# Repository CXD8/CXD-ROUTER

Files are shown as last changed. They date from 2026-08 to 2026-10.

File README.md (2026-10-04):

# CXD-ROUTER
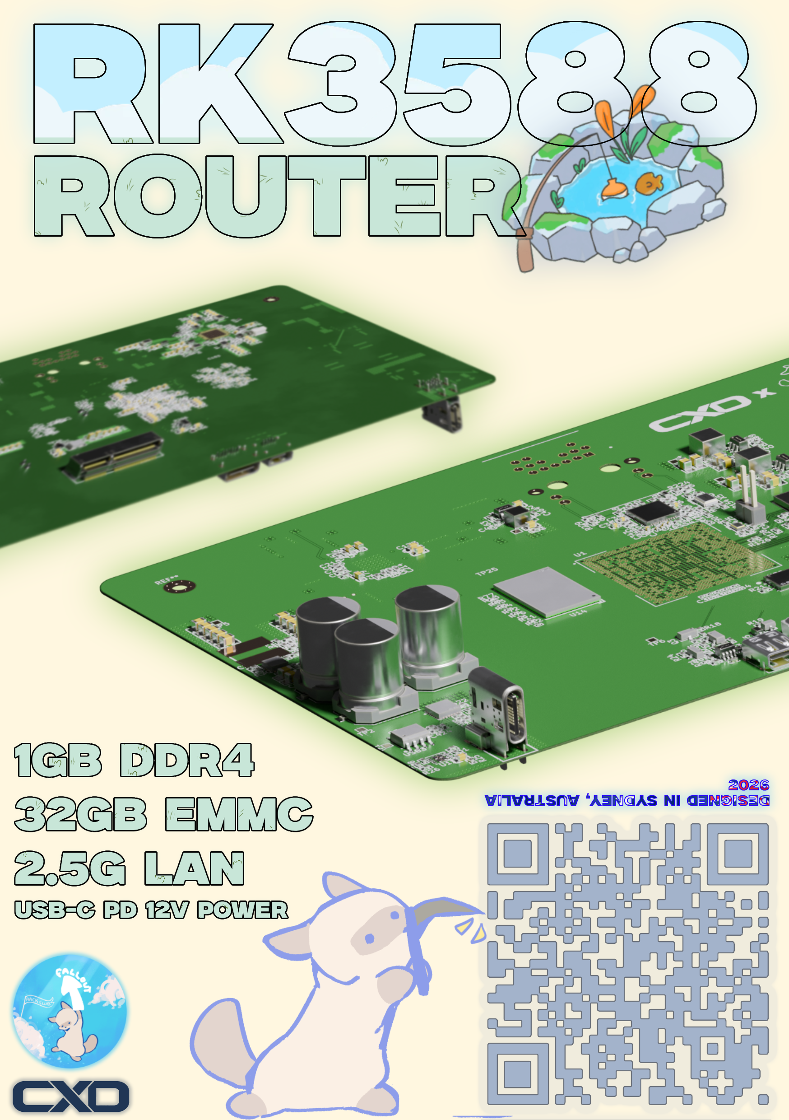
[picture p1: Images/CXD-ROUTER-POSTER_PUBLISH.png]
Poster


CXD-ROUTER is a high-speed, modular router built on a Rockchip RK3588 SoC, powered by USB-C PD.

Goal of Project:
Most consumer routers are locked down and unupgrade. I built this as a high-performance router where networking hardware (e.g., m.2 Wi-Fi modules) can be easily upgraded using M.2 slots without replacing the entire device.

## Specifications and Features

| Component | Details |
| :--- | :--- |
| **SoC** | Rockchip RK3588 |
| **Memory** | Onboard LPDDR4 memory |
| **Storage** | Onboard eMMC storage |
| **Upgradable Modules** | M.2 slots for 2.5GbE Ethernet and BE3600 Wi-Fi cards |
| **Power** | USB-C Power Delivery (PD) 12V |
| **I/O** | Mini HDMI, USB-C, 2.5G RJ45 |

## Firmware, flashing and setup

1. Follow Firefly's or Fygo's existing documentation to flash the RK3588 board (image itself cant be uploaded here due to size; flashing tools included in firmware folder):  
   [Fygo ROC-RK3588-PC Upgrade Firmware Guide](https://help.fygonas.com/articles/v1/contact/arm-rk-usb)  
   [Firefly ROC-RK3588-PC Upgrade Firmware Guide](https://wiki.t-firefly.com/en/ROC-RK3588-PC/upgrade_firmware.html)  
3. Connect peripherals (OPT: M.2 WiFi Card)
4. Plug in your network cable and Mini HDMI to a monitor.
5. Connect a 12v USB-C PD compatible power source to the board.

## Images
 **PCB:**
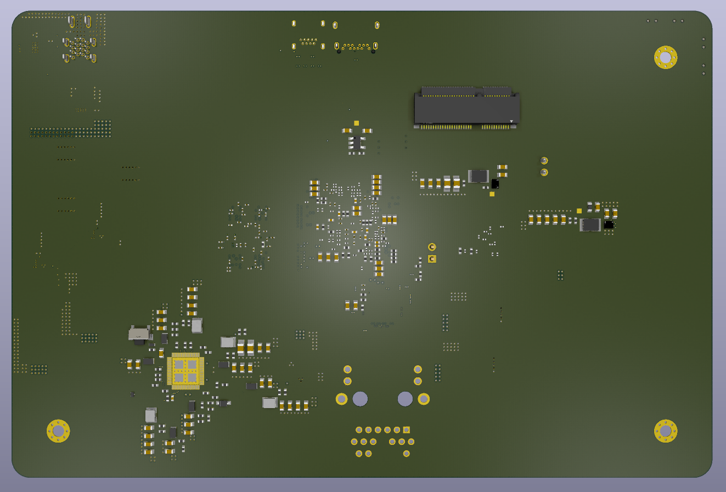
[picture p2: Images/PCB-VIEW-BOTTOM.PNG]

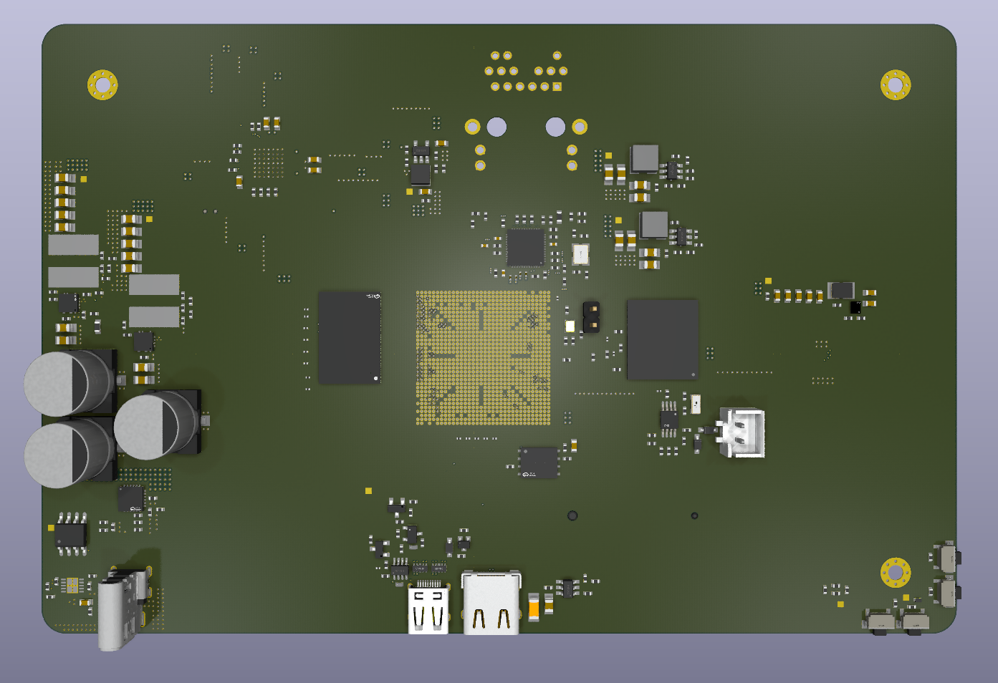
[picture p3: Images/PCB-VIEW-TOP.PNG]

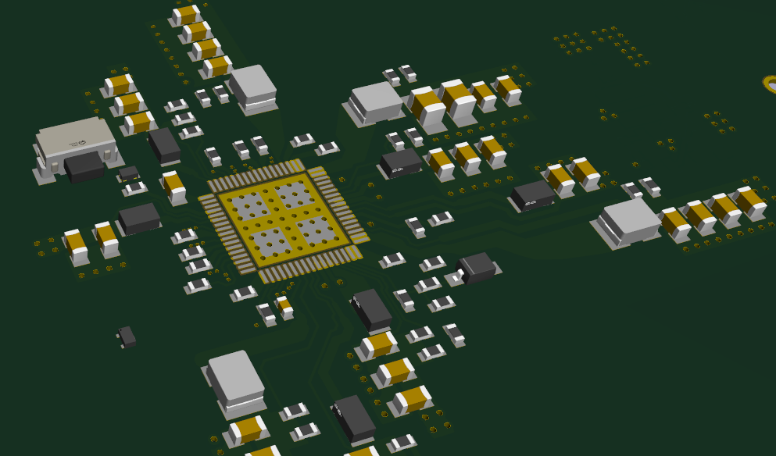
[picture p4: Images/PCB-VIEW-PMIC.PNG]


 **Housing:**
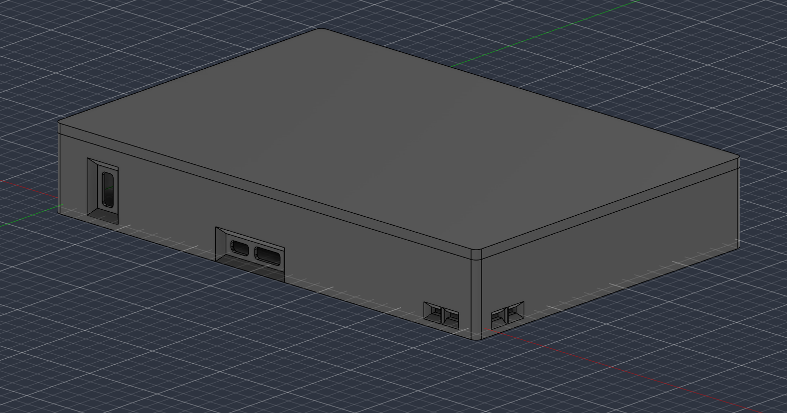
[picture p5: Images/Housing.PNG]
Housing


## Bill of Materials
|CXD-ROUTER-V1.0.0.csv| | | | | | | | | | | | | | | |
|---|---|---|---|---|---|---|---|---|---|---|---|---|---|---|---|
| | | | | | | | | | | | | | | | |
| | | | | | | | | | | | | | | | |
|Uploaded data | | | | | | | | | | | | | | | |
|LCSC# |Mrf# |Description |Package |Value |Quantity|Mfr. |Order Qty.|Unit Price(USD)|Ext.Price(USD)|Package |Min |Mult |SPQ |Description |Product Link |
|C49062 |CL03A104KP3NNNC |100nF X5R 10V 0201 |CL03A104KP3NNNC | |46 |Samsung Electro-Mechanics|100 |0.0047 |0.47 |0201 |100 |100 |10000  |100nF �10% 10V Ceramic Capacitor X5R 0201 |https://www.lcsc.com/product-detail/C49062.html |
|C59461 |CL10A226MQ8NRNC |22uF X5R 6.3V 0603 |CL10A226MQ8NRNC | |26 |Samsung Electro-Mechanics|40 |0.0313 |1.25 |0603 |20 |20 |4000 |22uF �20% 6.3V Ceramic Capacitor X5R 0603 |https://www.lcsc.com/product-detail/C59461.html |
|C190187 |CC0201KRX5R5BB104 |100nF 6.3V 0201 |RC0201FR-0749R9L | |16 |YAGEO |100 |0.0040 |0.40 |0201 |100 |100 |15000  |100nF �10% 6.3V Ceramic Capacitor X5R 0201 |https://www.lcsc.com/product-detail/C190187.html  |
|C541330 |CC0201KRX5R5BB105 |1uF 6.3V 0201 |RC0201FR-0749R9L | |15 |YAGEO |100 |0.0071 |0.71 |0201 |100 |100 |15000  |1uF �10% 6.3V Ceramic Capacitor X5R 0201 |https://www.lcsc.com/product-detail/C541330.html  |
|C315248 |CL05A106MP5NUNC |10uF X5R 4V 0402_BGA |RC0402JR-070RL | |13 |Samsung Electro-Mechanics|20 |0.0516 |1.03 |0402 |20 |20 |10000  |10uF �20% 10V Ceramic Capacitor X5R 0402 |https://www.lcsc.com/product-detail/C315248.html  |
|C3020456 |GRM188R60J226KEA0D |22uF 0603 6.3V X5R |GRM188R60J226KEA0D | |12 |muRata |20 |0.0488 |0.98 |0603 |20 |20 |4000 |22uF �10% 6.3V Ceramic Capacitor X5R 0603 |https://www.lcsc.com/product-detail/C3020456.html |
|C307380 |CL03A104KO3NNNC |100nF X5R 16V 0201 |RC0201FR-0749R9L | |11 |Samsung Electro-Mechanics|100 |0.0062 |0.62 |0201 |100 |100 |10000  |100nF �10% 16V Ceramic Capacitor X5R 0201 |https://www.lcsc.com/product-detail/C307380.html  |
|C318688 |CL21A226KPCLRNC |22uF 10V 0805 10% |CL21A226KPCLRNC | |11 |Samsung Electro-Mechanics|20 |0.0823 |1.65 |0805 |10 |10 |4000 |22uF �10% 10V Ceramic Capacitor X5R 0805 |https://www.lcsc.com/product-detail/C318688.html  |
|C190187 |CC0201KRX5R5BB104 |100nF 0201 6.3V |RC0201FR-0749R9L | |10 |YAGEO |100 |0.0040 |0.40 |0201 |100 |100 |15000  |100nF �10% 6.3V Ceramic Capacitor X5R 0201 |https://www.lcsc.com/product-detail/C190187.html  |
|C105882 |CC0402KRX5R9BB104 |100nF 50V 0402 |RC0402JR-070RL | |10 |YAGEO |50 |0.0155 |0.78 |0402 |50 |50 |10000  |100nF �10% 50V Ceramic Capacitor X5R 0402 |https://www.lcsc.com/product-detail/C105882.html  |
|C14445 |CL05A105KP5NNNC |1uF X5R 10V 0402 |FRC0402F1693TS | |10 |Samsung Electro-Mechanics|50 |0.0128 |0.64 |0402 |50 |50 |10000  |1uF �10% 10V Ceramic Capacitor X5R 0402 |https://www.lcsc.com/product-detail/C14445.html |
|C19702 |CL10A106KP8NNNC |10uF X5R 10V 0603 |CL10A106KP8NNNC | |9 |Samsung Electro-Mechanics|20 |0.0391 |0.78 |0603 |20 |20 |4000 |10uF �10% 10V Ceramic Capacitor X5R 0603 |https://www.lcsc.com/product-detail/C19702.html |
|C107372 |CL05A105KQ5NNNC |1uF X5R 6.3V 0201 |CL05A105KQ5NNNC | |8 |Samsung Electro-Mechanics|100 |0.0076 |0.76 |0402 |100 |100 |10000  |1uF �10% 6.3V Ceramic Capacitor X5R 0402 |https://www.lcsc.com/product-detail/C107372.html  |
|C49062 |CL03A104KP3NNNC |100nF X5R 100V 0201 |CL03A104KP3NNNC | |8 |Samsung Electro-Mechanics|100 |0.0047 |0.47 |0201 |100 |100 |10000  |100nF �10% 10V Ceramic Capacitor X5R 0201 |https://www.lcsc.com/product-detail/C49062.html |
|C3020456 |GRM188R60J226KEA0D |22uF X5R 6.3V 0603 |GRM188R60J226KEA0D | |8 |muRata |20 |0.0488 |0.98 |0603 |20 |20 |4000 |22uF �10% 6.3V Ceramic Capacitor X5R 0603 |https://www.lcsc.com/product-detail/C3020456.html |
|C440198 |GRM21BR61H106KE43L |10uF 50V 0805 |GRM21BR61H106KE43L | |8 |muRata |10 |0.3246 |3.25 |0805 |5 |5 |3000 |10uF �10% 50V Ceramic Capacitor X5R 0805 |https://www.lcsc.com/product-detail/C440198.html  |
|C49062 |CL03A104KP3NNNC |100nF 0201 10V X5R |CL03A104KP3NNNC | |7 |Samsung Electro-Mechanics|100 |0.0047 |0.47 |0201 |100 |100 |10000  |100nF �10% 10V Ceramic Capacitor X5R 0201 |https://www.lcsc.com/product-detail/C49062.html |
|C170151 |CL05A225KO5NQNC |16V 2.2uF 0402 |FRC0402F1693TS | |7 |Samsung Electro-Mechanics|50 |0.0291 |1.46 |0402 |50 |50 |10000  |2.2uF �10% 16V Ceramic Capacitor X5R 0402 |https://www.lcsc.com/product-detail/C170151.html  |
|C161455 |GRM033C80G105MEA2D |1uF 4V 0201 |RC0201FR-0749R9L | |6 |muRata |20 |0.0279 |0.56 |0201 |20 |20 |15000  |1uF �20% 4V Ceramic Capacitor X6S 0201 |https://www.lcsc.com/product-detail/C161455.html  |
|C541330 |CC0201KRX5R5BB105 |1uF X5R 6.3V 0201 |RC0201FR-0749R9L | |6 |YAGEO |100 |0.0071 |0.71 |0201 |100 |100 |15000  |1uF �10% 6.3V Ceramic Capacitor X5R 0201 |https://www.lcsc.com/product-detail/C541330.html  |
|C315248 |CL05A106MP5NUNC |10V 10uF 0402 |10uF_X5R_10V_0402 | |5 |Samsung Electro-Mechanics|20 |0.0516 |1.03 |0402 |20 |20 |10000  |10uF �20% 10V Ceramic Capacitor X5R 0402 |https://www.lcsc.com/product-detail/C315248.html  |
|C170151 |CL05A225KO5NQNC |2.2uF X5R 6.3V 0402 |FRC0402F1693TS | |5 |Samsung Electro-Mechanics|50 |0.0291 |1.46 |0402 |50 |50 |10000  |2.2uF �10% 16V Ceramic Capacitor X5R 0402 |https://www.lcsc.com/product-detail/C170151.html  |
|C14445 |CL05A105KP5NNNC |1uF X5R 6.3V 0402 |FRC0402F1693TS | |5 |Samsung Electro-Mechanics|50 |0.0128 |0.64 |0402 |50 |50 |10000  |1uF �10% 10V Ceramic Capacitor X5R 0402 |https://www.lcsc.com/product-detail/C14445.html |
|C526941 |CC0201JRX7R8BB102 |1nF 25V X7R 0201 |RC0201FR-0749R9L | |5 |YAGEO |100 |0.0052 |0.52 |0201 |100 |100 |15000  |1nF �5% 25V Ceramic Capacitor X7R 0201 |https://www.lcsc.com/product-detail/C526941.html  |
|C368809 |CL05A475KP5NRNC |4.7uF 10V 04024 |RC0402JR-070RL | |4 |Samsung Electro-Mechanics|50 |0.0170 |0.85 |0402 |50 |50 |10000  |4.7uF �10% 10V Ceramic Capacitor X5R 0402 |https://www.lcsc.com/product-detail/C368809.html  |
|C190187 |CC0201KRX5R5BB104 |100nF 0201 6.3V X5R |RC0201FR-0749R9L | |4 |YAGEO |100 |0.0040 |0.40 |0201 |100 |100 |15000  |100nF �10% 6.3V Ceramic Capacitor X5R 0201 |https://www.lcsc.com/product-detail/C190187.html  |
|C3845593 |GRM158R61A226ME15D |22uF X5R 10V |RC0402JR-070RL | |4 |muRata |4 |0.7950 |3.18 |0402 |1 |1 |8000 |22uF �20% 10V Ceramic Capacitor X5R 0402 |https://www.lcsc.com/product-detail/C3845593.html |
|C105882 |CC0402KRX5R9BB104 |100nF 0402 50V |RC0402JR-070RL | |4 |YAGEO |50 |0.0155 |0.78 |0402 |50 |50 |10000  |100nF �10% 50V Ceramic Capacitor X5R 0402 |https://www.lcsc.com/product-detail/C105882.html  |
|C49062 |CL03A104KP3NNNC |100nF 10V X5R �10% 0201 |CL03A104KP3NNNC | |4 |Samsung Electro-Mechanics|100 |0.0047 |0.47 |0201 |100 |100 |10000  |100nF �10% 10V Ceramic Capacitor X5R 0201 |https://www.lcsc.com/product-detail/C49062.html |
|C105882 |CC0402KRX5R9BB104 |100nF 0402 |RC0402JR-070RL | |3 |YAGEO |50 |0.0155 |0.78 |0402 |50 |50 |10000  |100nF �10% 50V Ceramic Capacitor X5R 0402 |https://www.lcsc.com/product-detail/C105882.html  |
|C124129 |GRM21BR61A476ME15L |10V 47uF 0805 |GRM21BR61A476ME15L | |3 |muRata |5 |0.5125 |2.56 |0805 |5 |5 |3000 |47uF �20% 10V Ceramic Capacitor X5R 0805 |https://www.lcsc.com/product-detail/C124129.html  |
|C318688 |CL21A226KPCLRNC |22uF 10V 0805 10% - DNP OPTIONAL|CL21A226KPCLRNC | |3 |Samsung Electro-Mechanics|10 |0.0823 |0.82 |0805 |10 |10 |4000 |22uF �10% 10V Ceramic Capacitor X5R 0805 |https://www.lcsc.com/product-detail/C318688.html  |
|C487410 |VKME1001K101MV |100uF 80V SMD |VKME1001K101MV | |3 |Ymin |5 |0.2976 |1.49 |SMD,D10xL10mm |5 |5 |500 |100uF �20% 80V Aluminum Electrolytic Capacitors 10000hrs@105? |https://www.lcsc.com/product-detail/C487410.html  |
|C14445 |CL05A105KP5NNNC |10V 1uF 402 |FRC0402F1693TS | |3 |Samsung Electro-Mechanics|50 |0.0128 |0.64 |0402 |50 |50 |10000  |1uF �10% 10V Ceramic Capacitor X5R 0402 |https://www.lcsc.com/product-detail/C14445.html |
|C19702 |CL10A106KP8NNNC |10V 10uF 0603 |CL10A106KP8NNNC | |3 |Samsung Electro-Mechanics|20 |0.0391 |0.78 |0603 |20 |20 |4000 |10uF �10% 10V Ceramic Capacitor X5R 0603 |https://www.lcsc.com/product-detail/C19702.html |
|C368809 |CL05A475KP5NRNC |4.7uF X5R 10V 0402 |RC0402JR-070RL | |2 |Samsung Electro-Mechanics|50 |0.0170 |0.85 |0402 |50 |50 |10000  |4.7uF �10% 10V Ceramic Capacitor X5R 0402 |https://www.lcsc.com/product-detail/C368809.html  |
|C469468 |CC0402MRX5R6BB475 |10V 4.7uF 0402 |FRC0402F1693TS | |2 |YAGEO |50 |0.0199 |1.00 |0402 |50 |50 |10000  |4.7uF �20% 10V Ceramic Capacitor X5R 0402 |https://www.lcsc.com/product-detail/C469468.html  |
|C161455 |GRM033C80G105MEA2D |1uF 0201 4V X5R |RC0201FR-0749R9L | |2 |muRata |20 |0.0279 |0.56 |0201 |20 |20 |15000  |1uF �20% 4V Ceramic Capacitor X6S 0201 |https://www.lcsc.com/product-detail/C161455.html  |
|C541466 |CC0402KRX5R5BB475 |4.7uF 6.3V 0402_BGA |RC0402JR-070RL | |2 |YAGEO |20 |0.0407 |0.81 |0402 |20 |20 |10000  |4.7uF �10% 6.3V Ceramic Capacitor X5R 0402 |https://www.lcsc.com/product-detail/C541466.html  |
|C541466 |CC0402KRX5R5BB475 |4.7uF X5R 6.3V 0402_BGA |RC0402JR-070RL | |2 |YAGEO |20 |0.0407 |0.81 |0402 |20 |20 |10000  |4.7uF �10% 6.3V Ceramic Capacitor X5R 0402 |https://www.lcsc.com/product-detail/C541466.html  |
|C71693 |GRM1555C1H221JA01D |220pF 0402 C0G 50V |RC0402JR-070RL | |2 |muRata |100 |0.0048 |0.48 |0402 |100 |100 |10000  |220pF �5% 50V Ceramic Capacitor C0G 0402 |https://www.lcsc.com/product-detail/C71693.html |
|C16780 |CL21A476MQYNNNE |47uF X5R 6.3V 0805 |CL21A476MQYNNNE | |2 |Samsung Electro-Mechanics|10 |0.1783 |1.78 |0805 |10 |10 |2000 |47uF �20% 6.3V Ceramic Capacitor X5R 0805 |https://www.lcsc.com/product-detail/C16780.html |
|C2941926 |GCM1555C1H101FA16D |100pF C0G 40V 0402 |FRC0402F1693TS | |2 |muRata |50 |0.0230 |1.15 |0402 |50 |50 |10000  |100pF �1% 50V Ceramic Capacitor C0G 0402 |https://www.lcsc.com/product-detail/C2941926.html |
|C526995 |CC0402JRNPO8BN102 |1nF 0402 C0G 25V |FRC0402F1693TS | |2 |YAGEO |100 |0.0119 |1.19 |0402 |100 |100 |10000  |1nF �5% 25V Ceramic Capacitor NP0 0402 |https://www.lcsc.com/product-detail/C526995.html  |
|C190187 |CC0201KRX5R5BB104 |100nF 6.3V X5R 0201 |RC0201FR-0749R9L | |2 |YAGEO |100 |0.0040 |0.40 |0201 |100 |100 |15000  |100nF �10% 6.3V Ceramic Capacitor X5R 0201 |https://www.lcsc.com/product-detail/C190187.html  |
|C701263 |GRM033R61E224KE01D |220nF 0201 10% |RC0201FR-0749R9L | |2 |muRata |50 |0.0144 |0.72 |0201 |50 |50 |15000  |220nF �10% 25V Ceramic Capacitor X5R 0201 |https://www.lcsc.com/product-detail/C701263.html  |
|C14445 |CL05A105KP5NNNC |10V 1uF 0402 |FRC0402F1693TS | |2 |Samsung Electro-Mechanics|50 |0.0128 |0.64 |0402 |50 |50 |10000  |1uF �10% 10V Ceramic Capacitor X5R 0402 |https://www.lcsc.com/product-detail/C14445.html |
|C326662 |CC0402FRNPO9BN120 |12pF NP0 1% 0402 |RC0402FR-071KL | |2 |YAGEO |50 |0.0125 |0.63 |0402 |50 |50 |10000  |12pF �1% 50V Ceramic Capacitor NP0 0402 |https://www.lcsc.com/product-detail/C326662.html  |
|C281765 |CC0402BRNPO9BN8R0 |50V 8pF NP0 0402 |RC0402FR-071KL | |2 |YAGEO |100 |0.0090 |0.90 |0402 |100 |100 |10000  |8pF 50V Ceramic Capacitor NP0 0402 |https://www.lcsc.com/product-detail/C281765.html  |
|C541330 |CC0201KRX5R5BB105 |1uF X5R 10% 0201 |RC0201FR-0749R9L | |1 |YAGEO |100 |0.0071 |0.71 |0201 |100 |100 |15000  |1uF �10% 6.3V Ceramic Capacitor X5R 0201 |https://www.lcsc.com/product-detail/C541330.html  |
|C307380 |CL03A104KO3NNNC |100nF X5R 16V - DNP |RC0201FR-0749R9L | |1 |Samsung Electro-Mechanics|100 |0.0062 |0.62 |0201 |100 |100 |10000  |100nF �10% 16V Ceramic Capacitor X5R 0201 |https://www.lcsc.com/product-detail/C307380.html  |
|C105882 |CC0402KRX5R9BB104 |100nF 50V  0402 |RC0402JR-070RL | |1 |YAGEO |50 |0.0155 |0.78 |0402 |50 |50 |10000  |100nF �10% 50V Ceramic Capacitor X5R 0402 |https://www.lcsc.com/product-detail/C105882.html  |
|C29936 |CL10B105KA8NNNC |1uF 25V 6030 |CL10B105KA8NNNC | |1 |Samsung Electro-Mechanics|50 |0.0225 |1.13 |0603 |50 |50 |4000 |1uF �10% 25V Ceramic Capacitor X7R 0603 |https://www.lcsc.com/product-detail/C29936.html |
|C161488 |GRM033R71E222KA12D |2.2nF 25V 0201 |RC0201FR-0747KL | |1 |muRata |100 |0.0064 |0.64 |0201 |100 |100 |15000  |2.2nF �10% 25V Ceramic Capacitor X7R 0201 |https://www.lcsc.com/product-detail/C161488.html  |
|C315248 |CL05A106MP5NUNC |10uF 4V 0402 20% |RC0402JR-070RL | |1 |Samsung Electro-Mechanics|20 |0.0516 |1.03 |0402 |20 |20 |10000  |10uF �20% 10V Ceramic Capacitor X5R 0402 |https://www.lcsc.com/product-detail/C315248.html  |
|C541466 |CC0402KRX5R5BB475 |4.7uF 0402_BGA 6.3V X5R |RC0402JR-070RL | |1 |YAGEO |20 |0.0407 |0.81 |0402 |20 |20 |10000  |4.7uF �10% 6.3V Ceramic Capacitor X5R 0402 |https://www.lcsc.com/product-detail/C541466.html  |
|C29936 |CL10B105KA8NNNC |1uF 25V 0603 |CL10B105KA8NNNC | |1 |Samsung Electro-Mechanics|50 |0.0225 |1.13 |0603 |50 |50 |4000 |1uF �10% 25V Ceramic Capacitor X7R 0603 |https://www.lcsc.com/product-detail/C29936.html |
|C883598 |GRM31CR61A107MEA8L |100uF 10V 1206 |GRM31CR61A107MEA8L | |1 |muRata |1 |0.5126 |0.51 |1206 |1 |1 |2000 |100uF �20% 10V Ceramic Capacitor X5R 1206 |https://www.lcsc.com/product-detail/C883598.html  |
|C107372 |CL05A105KQ5NNNC |1uF X5R 6.3V 0402 |CL05A105KQ5NNNC | |1 |Samsung Electro-Mechanics|100 |0.0076 |0.76 |0402 |100 |100 |10000  |1uF �10% 6.3V Ceramic Capacitor X5R 0402 |https://www.lcsc.com/product-detail/C107372.html  |
|C469468 |CC0402MRX5R6BB475 |4.7uF 0402 10V X5R |FRC0402F1693TS | |1 |YAGEO |50 |0.0199 |1.00 |0402 |50 |50 |10000  |4.7uF �20% 10V Ceramic Capacitor X5R 0402 |https://www.lcsc.com/product-detail/C469468.html  |
|C15195 |CL05B103KB5NNNC |10nF X7R 25V 0402 |FRC0402F1693TS | |1 |Samsung Electro-Mechanics|100 |0.0054 |0.54 |0402 |100 |100 |10000  |10nF �10% 50V Ceramic Capacitor X7R 0402 |https://www.lcsc.com/product-detail/C15195.html |
|C307339 |CL05B473KB5VPNC |47nF 0402 |RC0402JR-070RL | |1 |Samsung Electro-Mechanics|50 |0.0142 |0.71 |0402 |50 |50 |10000  |47nF �10% 50V Ceramic Capacitor X7R 0402 |https://www.lcsc.com/product-detail/C307339.html  |
|C106998 |CC0402JRNPO9BN151 |150pF 0402 50V |RC0402JR-070RL | |1 |YAGEO |100 |0.0047 |0.47 |0402 |100 |100 |10000  |150pF �5% 50V Ceramic Capacitor NP0 0402 |https://www.lcsc.com/product-detail/C106998.html  |
|C76943 |GRM033R71E102KA01D |1nF X5R 25V 0201 |RC0201FR-07240RL | |1 |muRata |100 |0.0098 |0.98 |0201 |100 |100 |15000  |1nF �10% 25V Ceramic Capacitor X7R 0201 |https://www.lcsc.com/product-detail/C76943.html |
|C107028 |CC0402KRX7R9BB332 |3.3nF 50V X7R |RC0402FR-071KL | |1 |YAGEO |100 |0.0041 |0.41 |0402 |100 |100 |10000  |3.3nF �10% 50V Ceramic Capacitor X7R 0402 |https://www.lcsc.com/product-detail/C107028.html  |
|C106208 |CC0402KRX7R9BB472 |4.7nF X7R 10% 0402 |RC0402FR-071KL | |1 |YAGEO |100 |0.0033 |0.33 |0402 |100 |100 |10000  |4.7nF �10% 50V Ceramic Capacitor X7R 0402 |https://www.lcsc.com/product-detail/C106208.html  |
|C2941926 |GCM1555C1H101FA16D |100pF 50V C0G 0402 |FRC0402F1693TS | |1 |muRata |50 |0.0230 |1.15 |0402 |50 |50 |10000  |100pF �1% 50V Ceramic Capacitor C0G 0402 |https://www.lcsc.com/product-detail/C2941926.html |
|C326662 |CC0402FRNPO9BN120 |12pF NP0 0402 |RC0402FR-071KL | |1 |YAGEO |50 |0.0125 |0.63 |0402 |50 |50 |10000  |12pF �1% 50V Ceramic Capacitor NP0 0402 |https://www.lcsc.com/product-detail/C326662.html  |
|C326662 |CC0402FRNPO9BN120 |DNP |RC0402FR-071KL | |1 |YAGEO |50 |0.0125 |0.63 |0402 |50 |50 |10000  |12pF �1% 50V Ceramic Capacitor NP0 0402 |https://www.lcsc.com/product-detail/C326662.html  |
|C60485 |RC0402JR-070RL |0R 0402 |RC0402JR-070RL | |13 |YAGEO |100 |0.0049 |0.49 |0402 |100 |100 |10000  |0? 62.5mW 50V Thick Film Resistor �5% 0402 Chip Resistor - Surface Mount RoHS |https://www.lcsc.com/product-detail/C60485.html |
|C60485 |RC0402JR-070RL |0K 0402 |RC0402JR-070RL | |7 |YAGEO |100 |0.0049 |0.49 |0402 |100 |100 |10000  |0? 62.5mW 50V Thick Film Resistor �5% 0402 Chip Resistor - Surface Mount RoHS |https://www.lcsc.com/product-detail/C60485.html |
|C60491 |RC0402FR-07100KL |100K 0402 |RC0402FR-07100KL | |7 |YAGEO |100 |0.0062 |0.62 |0402 |100 |100 |10000  |100k? 62.5mW 50V Thick Film Resistor �100ppm/? �1% 0402 Chip Resistor - Surface Mount RoHS |https://www.lcsc.com/product-detail/C60491.html |
|C60490 |RC0402FR-0710KL |10K 0402 |RC0402FR-0710KL | |6 |YAGEO |100 |0.0059 |0.59 |0402 |100 |100 |10000  |62.5mW 10k? 50V Thick Film Resistor �100ppm/? �1% 0402 Chip Resistor - Surface Mount RoHS |https://www.lcsc.com/product-detail/C60490.html |
|C105871 |RC0402FR-074K7L |4.7K 0402 |RC0402FR-074K7L | |5 |YAGEO |100 |0.0048 |0.48 |0402 |100 |100 |10000  |4.7k? �1% 62.5mW 0402 Thick Film Resistor |https://www.lcsc.com/product-detail/C105871.html  |
|C155745 |RC0201FR-07240RL |240R 0201 1% |RC0201FR-07240RL | |4 |YAGEO |100 |0.0023 |0.23 |0201 |100 |100 |10000  |50mW 240? 25V Thick Film Resistor �1% �200ppm/? 0201 Chip Resistor - Surface Mount RoHS |https://www.lcsc.com/product-detail/C155745.html  |
|C106232 |RC0402FR-07100RL |100R 0402 |RC0402FR-07100RL | |4 |YAGEO |100 |0.0039 |0.39 |0402 |100 |100 |10000  |100? 62.5mW 50V Thick Film Resistor �100ppm/? �1% 0402 Chip Resistor - Surface Mount RoHS |https://www.lcsc.com/product-detail/C106232.html  |
|C60491 |RC0402FR-07100KL |100R 1% 0402 |RC0402FR-07100KL | |4 |YAGEO |100 |0.0062 |0.62 |0402 |100 |100 |10000  |100k? 62.5mW 50V Thick Film Resistor �100ppm/? �1% 0402 Chip Resistor - Surface Mount RoHS |https://www.lcsc.com/product-detail/C60491.html |
|C60491 |RC0402FR-07100KL |100K 0402 1% |RC0402FR-07100KL | |4 |YAGEO |100 |0.0062 |0.62 |0402 |100 |100 |10000  |100k? 62.5mW 50V Thick Film Resistor �100ppm/? �1% 0402 Chip Resistor - Surface Mount RoHS |https://www.lcsc.com/product-detail/C60491.html |
|C155744 |RC0201FR-0749R9L |49.9R 1% 0201 |RC0201FR-0749R9L | |4 |YAGEO |100 |0.0013 |0.13 |0201 |100 |100 |10000  |50mW 49.9? 25V Thick Film Resistor �1% �200ppm/? 0201 Chip Resistor - Surface Mount RoHS |https://www.lcsc.com/product-detail/C155744.html  |
|C114762 |RC0402FR-072K2L |2.2K 0402 1% |RC0402FR-072K2L | |4 |YAGEO |100 |0.0014 |0.14 |0402 |100 |100 |10000  |62.5mW 2.2k? 50V Thick Film Resistor �100ppm/? �1% 0402 Chip Resistor - Surface Mount RoHS |https://www.lcsc.com/product-detail/C114762.html  |
|C60489 |RC0402JR-0710KL |10K 5% 0201 |RC0402JR-0710KL | |3 |YAGEO |100 |0.0037 |0.37 |0402 |100 |100 |10000  |62.5mW 10k? 50V Thick Film Resistor �100ppm/? �5% 0402 Chip Resistor - Surface Mount RoHS |https://www.lcsc.com/product-detail/C60489.html |
|C60489 |RC0402JR-0710KL |10K 0402 5% |RC0402JR-0710KL | |3 |YAGEO |100 |0.0037 |0.37 |0402 |100 |100 |10000  |62.5mW 10k? 50V Thick Film Resistor �100ppm/? �5% 0402 Chip Resistor - Surface Mount RoHS |https://www.lcsc.com/product-detail/C60489.html |
|C60485 |RC0402JR-070RL |DNP |RC0402JR-070RL | |3 |YAGEO |100 |0.0049 |0.49 |0402 |100 |100 |10000  |0? 62.5mW 50V Thick Film Resistor �5% 0402 Chip Resistor - Surface Mount RoHS |https://www.lcsc.com/product-detail/C60485.html |
|C106234 |RC0402JR-07100KL |100K 5% 0402 |RC0402JR-07100KL | |2 |YAGEO |100 |0.0028 |0.28 |0402 |100 |100 |10000  |100k? �5% 62.5mW 0402 Thick Film Resistor |https://www.lcsc.com/product-detail/C106234.html  |
|C60491 |RC0402FR-07100KL |100K 1% 0402 |RC0402FR-07100KL | |2 |YAGEO |100 |0.0062 |0.62 |0402 |100 |100 |10000  |100k? 62.5mW 50V Thick Film Resistor �100ppm/? �1% 0402 Chip Resistor - Surface Mount RoHS |https://www.lcsc.com/product-detail/C60491.html |
|C93945 |RC0402FR-07120KL |120K 1% 0402 |RC0402FR-07120KL | |2 |YAGEO |100 |0.0055 |0.55 |0402 |100 |100 |10000  |62.5mW 120k? 50V Thick Film Resistor �100ppm/? �1% 0402 Chip Resistor - Surface Mount RoHS |https://www.lcsc.com/product-detail/C93945.html |
|C728556 |RT0402BRD07200KL |200K 0402 0.1% |RT0402BRD07200KL | |2 |YAGEO |50 |0.0263 |1.32 |0402 |50 |50 |10000  |200k? 62.5mW 50V Thin Film Resistor �25ppm/? �0.1% 0402 Chip Resistor - Surface Mount RoHS |https://www.lcsc.com/product-detail/C728556.html  |
|C60490 |RC0402FR-0710KL |10K 1% 0402 |RC0402FR-0710KL | |2 |YAGEO |100 |0.0059 |0.59 |0402 |100 |100 |10000  |62.5mW 10k? 50V Thick Film Resistor �100ppm/? �1% 0402 Chip Resistor - Surface Mount RoHS |https://www.lcsc.com/product-detail/C60490.html |
|C106234 |RC0402JR-07100KL |100K 0402 5% |RC0402JR-07100KL | |2 |YAGEO |100 |0.0028 |0.28 |0402 |100 |100 |10000  |100k? �5% 62.5mW 0402 Thick Film Resistor |https://www.lcsc.com/product-detail/C106234.html  |
|C93945 |RC0402FR-07120KL |120K 50V �1% 0402 |RC0402FR-07120KL | |2 |YAGEO |100 |0.0055 |0.55 |0402 |100 |100 |10000  |62.5mW 120k? 50V Thick Film Resistor �100ppm/? �1% 0402 Chip Resistor - Surface Mount RoHS |https://www.lcsc.com/product-detail/C93945.html |
|C106235 |RC0402FR-071KL |1K 0402 1% |RC0402FR-071KL | |2 |YAGEO |100 |0.0062 |0.62 |0402 |100 |100 |10000  |1k? 62.5mW 50V Thick Film Resistor �100ppm/? �1% 0402 Chip Resistor - Surface Mount RoHS |https://www.lcsc.com/product-detail/C106235.html  |
|C60490 |RC0402FR-0710KL |10K 0402 DNP |RC0402FR-0710KL | |2 |YAGEO |100 |0.0059 |0.59 |0402 |100 |100 |10000  |62.5mW 10k? 50V Thick Film Resistor �100ppm/? �1% 0402 Chip Resistor - Surface Mount RoHS |https://www.lcsc.com/product-detail/C60490.html |
|C60485 |RC0402JR-070RL |0R 0402 DNP |RC0402JR-070RL | |2 |YAGEO |100 |0.0049 |0.49 |0402 |100 |100 |10000  |0? 62.5mW 50V Thick Film Resistor �5% 0402 Chip Resistor - Surface Mount RoHS |https://www.lcsc.com/product-detail/C60485.html |
|C482112 |CRCW0402249RFKED |249R 0402 |CRCW0402249RFKED | |2 |VISHAY |100 |0.0070 |0.70 |0402 |100 |100 |10000  |249? 62.5mW 50V Thick Film Resistor �1% �100ppm/? 0402 Chip Resistor - Surface Mount RoHS |https://www.lcsc.com/product-detail/C482112.html  |
|C138139 |RC0201FR-0747KL |47K 0201 1% - DNP |RC0201FR-0747KL | |1 |YAGEO |100 |0.0030 |0.30 |0201 |100 |100 |10000  |50mW 47k? 25V Thick Film Resistor �1% �200ppm/? 0201 Chip Resistor - Surface Mount RoHS |https://www.lcsc.com/product-detail/C138139.html  |
|C482107 |CRCW040222R0JNED |22R 0402 5% |CRCW040222R0JNED | |1 |VISHAY |100 |0.0063 |0.63 |0402 |100 |100 |10000  |22? 62.5mW 50V Thick Film Resistor �5% �200ppm/? 0402 Chip Resistor - Surface Mount RoHS |https://www.lcsc.com/product-detail/C482107.html  |
|C137961 |RC0402FR-07510KL |510K 1% 0402 |RC0402FR-07510KL | |1 |YAGEO |100 |0.0044 |0.44 |0402 |100 |100 |10000  |510k? 62.5mW 50V Thick Film Resistor �100ppm/? �1% 0402 Chip Resistor - Surface Mount RoHS |https://www.lcsc.com/product-detail/C137961.html  |
|C105637 |RC0402JR-071KL |1K 0402 5% |RC0402JR-071KL | |1 |YAGEO |100 |0.0052 |0.52 |0402 |100 |100 |10000  |1k? �5% 62.5mW 0402 Thick Film Resistor |https://www.lcsc.com/product-detail/C105637.html  |
|C137902 |RC0402JR-0720KL |20K 0402 5% |RC0402JR-0720KL | |1 |YAGEO |100 |0.0036 |0.36 |0402 |100 |100 |10000  |20k? 62.5mW 50V Thick Film Resistor �100ppm/? �5% 0402 Chip Resistor - Surface Mount RoHS |https://www.lcsc.com/product-detail/C137902.html  |
|C137891 |RC0402JR-0727KL |27K 0402 |RC0402JR-0727KL | |1 |YAGEO |100 |0.0025 |0.25 |0402 |100 |100 |10000  |27k? 62.5mW 50V Thick Film Resistor �100ppm/? �5% 0402 Chip Resistor - Surface Mount RoHS |https://www.lcsc.com/product-detail/C137891.html  |
|C60485 |RC0402JR-070RL |0R 0402 5% |RC0402JR-070RL | |1 |YAGEO |100 |0.0049 |0.49 |0402 |100 |100 |10000  |0? 62.5mW 50V Thick Film Resistor �5% 0402 Chip Resistor - Surface Mount RoHS |https://www.lcsc.com/product-detail/C60485.html |
|C138066 |RC0402FR-0710RL |10? 0402 50V |RC0402FR-0710RL | |1 |YAGEO |100 |0.0059 |0.59 |0402 |100 |100 |10000  |10? 62.5mW 50V Thick Film Resistor �1% �200ppm/? 0402 Chip Resistor - Surface Mount RoHS |https://www.lcsc.com/product-detail/C138066.html  |
|C105872 |RC0402FR-075K1L |5.1K 0402 50V |RC0402FR-075K1L | |1 |YAGEO |100 |0.0054 |0.54 |0402 |100 |100 |10000  |5.1k? 62.5mW 50V Thick Film Resistor �100ppm/? �1% 0402 Chip Resistor - Surface Mount RoHS |https://www.lcsc.com/product-detail/C105872.html  |
|C137969 |RC0402FR-0749K9L |49.9 0402 50V |RC0402FR-0749K9L | |1 |YAGEO |100 |0.0056 |0.56 |0402 |100 |100 |10000  |62.5mW 49.9k? 50V Thick Film Resistor �100ppm/? �1% 0402 Chip Resistor - Surface Mount RoHS |https://www.lcsc.com/product-detail/C137969.html  |
|C54831 |0402WGF1402TCE |12K +-1% 0402 |0402WGF1402TCE | |1 |UNI-ROYAL |100 |0.0039 |0.39 |0402 |100 |100 |10000  |14k? �1% 62.5mW 0402 Thick Film Resistor |https://www.lcsc.com/product-detail/C54831.html |
|C137947 |RC0402FR-0768KL |68K 0402 1% |RC0402FR-0768KL | |1 |YAGEO |100 |0.0046 |0.46 |0402 |100 |100 |10000  |68k? 62.5mW 50V Thick Film Resistor �100ppm/? �1% 0402 Chip Resistor - Surface Mount RoHS |https://www.lcsc.com/product-detail/C137947.html  |
|C130276 |RC0402FR-0733K2L |33.2K 0402 |RC0402FR-0733K2L | |1 |YAGEO |100 |0.0014 |0.14 |0402 |100 |100 |10000  |62.5mW 33.2k? 50V Thick Film Resistor �100ppm/? �1% 0402 Chip Resistor - Surface Mount RoHS |https://www.lcsc.com/product-detail/C130276.html  |
|C114760 |RC0402FR-0712KL |12K 0402 1% |RC0402FR-0712KL | |1 |YAGEO |100 |0.0053 |0.53 |0402 |100 |100 |10000  |12k? 62.5mW 50V Thick Film Resistor �100ppm/? �1% 0402 Chip Resistor - Surface Mount RoHS |https://www.lcsc.com/product-detail/C114760.html  |
|C137987 |RC0402FR-073KL |3K 0402 |RC0402FR-073KL | |1 |YAGEO |100 |0.0052 |0.52 |0402 |100 |100 |10000  |62.5mW 3k? 50V Thick Film Resistor �100ppm/? �1% 0402 Chip Resistor - Surface Mount RoHS |https://www.lcsc.com/product-detail/C137987.html  |
|C93940 |RC0402FR-076K8L |6.8K 0402 |RC0402FR-076K8L | |1 |YAGEO |100 |0.0054 |0.54 |0402 |100 |100 |10000  |62.5mW 6.8k? 50V Thick Film Resistor �100ppm/? �1% 0402 Chip Resistor - Surface Mount RoHS |https://www.lcsc.com/product-detail/C93940.html |
|C2100703 |AF0402FR-07511KL |511K 0402 1% |AF0402FR-07511KL | |1 |YAGEO |100 |0.0047 |0.47 |0402 |100 |100 |10000  |511k? 62.5mW 50V Thick Film Resistor �100ppm/? �1% 0402 Chip Resistor - Surface Mount RoHS |https://www.lcsc.com/product-detail/C2100703.html |
|C2984407 |ARG02BTC1053 |105K 0402 0.1% |ARG02BTC1053 | |1 |Viking |50 |0.0197 |0.99 |0402 |50 |50 |10000  |105k? �0.1% 62.5mW 0402 Thin Film Resistor |https://www.lcsc.com/product-detail/C2984407.html |
|C155745 |RC0201FR-07240RL |240R 1% 0201 |RC0201FR-07240RL | |1 |YAGEO |100 |0.0023 |0.23 |0201 |100 |100 |10000  |50mW 240? 25V Thick Film Resistor �1% �200ppm/? 0201 Chip Resistor - Surface Mount RoHS |https://www.lcsc.com/product-detail/C155745.html  |
|C93942 |RC0402FR-0720KL |20K 0402 1% |RC0402FR-0720KL | |1 |YAGEO |100 |0.0032 |0.32 |0402 |100 |100 |10000  |20k? 62.5mW 50V Thick Film Resistor �100ppm/? �1% 0402 Chip Resistor - Surface Mount RoHS |https://www.lcsc.com/product-detail/C93942.html |
|C114760 |RC0402FR-0712KL |12K 0402 |RC0402FR-0712KL | |1 |YAGEO |100 |0.0053 |0.53 |0402 |100 |100 |10000  |12k? 62.5mW 50V Thick Film Resistor �100ppm/? �1% 0402 Chip Resistor - Surface Mount RoHS |https://www.lcsc.com/product-detail/C114760.html  |
|C138139 |RC0201FR-0747KL |47K 0402 |RC0201FR-0747KL | |1 |YAGEO |100 |0.0030 |0.30 |0201 |100 |100 |10000  |50mW 47k? 25V Thick Film Resistor �1% �200ppm/? 0201 Chip Resistor - Surface Mount RoHS |https://www.lcsc.com/product-detail/C138139.html  |
|C2974012 |FRC0402F1693TS |169K 0402 |FRC0402F1693TS | |1 |FOJAN |100 |0.0018 |0.18 |0402 |100 |100 |10000  |169k? �1% 62.5mW 0402 Thick Film Resistor |https://www.lcsc.com/product-detail/C2974012.html |
|C861351 |RT0603BRD0736K1L |36.1k 0603 |RT0603BRD0736K1L | |1 |YAGEO |20 |0.0319 |0.64 |0603 |20 |20 |5000 |36.1k? 100mW 75V Thin Film Resistor �25ppm/? �0.1% 0603 Chip Resistor - Surface Mount RoHS |https://www.lcsc.com/product-detail/C861351.html  |
|C138163 |RC0201FR-07200KL |200K 1% |RC0201FR-07200KL | |1 |YAGEO |100 |0.0035 |0.35 |0201 |100 |100 |10000  |50mW 200k? 25V Thick Film Resistor �1% �200ppm/? 0201 Chip Resistor - Surface Mount RoHS |https://www.lcsc.com/product-detail/C138163.html  |
|C138010 |RC0402FR-07300RL |300? 1% 0402 |RC0402FR-07300RL | |1 |YAGEO |100 |0.0051 |0.51 |0402 |100 |100 |10000  |62.5mW 300? 50V Thick Film Resistor �100ppm/? �1% 0402 Chip Resistor - Surface Mount RoHS |https://www.lcsc.com/product-detail/C138010.html  |
|C138033 |RC0402FR-071ML |1M? 1% 0402 |RC0402FR-071ML | |1 |YAGEO |100 |0.0055 |0.55 |0402 |100 |100 |10000  |62.5mW 1M? 50V Thick Film Resistor �100ppm/? �1% 0402 Chip Resistor - Surface Mount RoHS |https://www.lcsc.com/product-detail/C138033.html  |
|C114761 |RC0402FR-0715KL |15K 0402 1% |RC0402FR-0715KL | |1 |YAGEO |100 |0.0037 |0.37 |0402 |100 |100 |10000  |15k? 62.5mW 50V Thick Film Resistor �100ppm/? �1% 0402 Chip Resistor - Surface Mount RoHS |https://www.lcsc.com/product-detail/C114761.html  |
|C145071 |RC0402FR-072K49L |2.49K 0402 % |RC0402FR-072K49L | |1 |YAGEO |100 |0.0014 |0.14 |0402 |100 |100 |10000  |2.49k? �1% 62.5mW 0402 Thick Film Resistor |https://www.lcsc.com/product-detail/C145071.html  |
|C93942 |RC0402FR-0720KL |20K 1% 0402 |RC0402FR-0720KL | |1 |YAGEO |100 |0.0032 |0.32 |0402 |100 |100 |10000  |20k? 62.5mW 50V Thick Film Resistor �100ppm/? �1% 0402 Chip Resistor - Surface Mount RoHS |https://www.lcsc.com/product-detail/C93942.html |
|C852795 |RT0402BRD0745K3L |45.3K 50V 0402 1% |RT0402BRD0745K3L | |1 |YAGEO |50 |0.0259 |1.30 |0402 |50 |50 |10000  |45.3k? 63mW 50V Thin Film Resistor �25ppm/? �0.1% 0402 Chip Resistor - Surface Mount RoHS |https://www.lcsc.com/product-detail/C852795.html  |
|C60490 |RC0402FR-0710KL |10K 50V 1% 0402 |RC0402FR-0710KL | |1 |YAGEO |100 |0.0059 |0.59 |0402 |100 |100 |10000  |62.5mW 10k? 50V Thick Film Resistor �100ppm/? �1% 0402 Chip Resistor - Surface Mount RoHS |https://www.lcsc.com/product-detail/C60490.html |
|C850915 |AT0402BRD0726K1L |26.1K |AT0402BRD0726K1L | |1 |YAGEO |10 |0.0666 |0.67 |0402 |10 |10 |10000  |26.1k? �0.1% 62.5mW 0402 Thin Film Resistor AEC-Q200 |https://www.lcsc.com/product-detail/C850915.html  |
|C852656 |RT0402BRD0723K7L |23.7K 0402 |RT0402BRD0723K7L | |1 |YAGEO |50 |0.0258 |1.29 |0402 |50 |50 |10000  |62.5mW 23.7k? 50V Thin Film Resistor �25ppm/? �0.1% 0402 Chip Resistor - Surface Mount RoHS |https://www.lcsc.com/product-detail/C852656.html  |
|C130276 |RC0402FR-0733K2L |33.2K 1% 0402 |RC0402FR-0733K2L | |1 |YAGEO |100 |0.0014 |0.14 |0402 |100 |100 |10000  |62.5mW 33.2k? 50V Thick Film Resistor �100ppm/? �1% 0402 Chip Resistor - Surface Mount RoHS |https://www.lcsc.com/product-detail/C130276.html  |
|C93945 |RC0402FR-07120KL |120K 0402 |RC0402FR-07120KL | |1 |YAGEO |100 |0.0055 |0.55 |0402 |100 |100 |10000  |62.5mW 120k? 50V Thick Film Resistor �100ppm/? �1% 0402 Chip Resistor - Surface Mount RoHS |https://www.lcsc.com/product-detail/C93945.html |
|C60491 |RC0402FR-07100KL |100K 50V 0402 |RC0402FR-07100KL | |1 |YAGEO |100 |0.0062 |0.62 |0402 |100 |100 |10000  |100k? 62.5mW 50V Thick Film Resistor �100ppm/? �1% 0402 Chip Resistor - Surface Mount RoHS |https://www.lcsc.com/product-detail/C60491.html |
|C93945 |RC0402FR-07120KL |120K 50V 0402 |RC0402FR-07120KL | |1 |YAGEO |100 |0.0055 |0.55 |0402 |100 |100 |10000  |62.5mW 120k? 50V Thick Film Resistor �100ppm/? �1% 0402 Chip Resistor - Surface Mount RoHS |https://www.lcsc.com/product-detail/C93945.html |
|C93929 |RC0402JR-0722RL |22R 0402 |RC0402JR-0722RL | |1 |YAGEO |100 |0.0011 |0.11 |0402 |100 |100 |10000  |22? 62.5mW 50V Thick Film Resistor �100ppm/? �5% 0402 Chip Resistor - Surface Mount RoHS |https://www.lcsc.com/product-detail/C93929.html |
|C138139 |RC0201FR-0747KL |47K 0201 |RC0201FR-0747KL | |1 |YAGEO |100 |0.0030 |0.30 |0201 |100 |100 |10000  |50mW 47k? 25V Thick Film Resistor �1% �200ppm/? 0201 Chip Resistor - Surface Mount RoHS |https://www.lcsc.com/product-detail/C138139.html  |
|C276273 |RC0402FR-07510RL |510R 1% 0402 |RC0402FR-07510RL | |1 |YAGEO |100 |0.0056 |0.56 |0402 |100 |100 |10000  |62.5mW 510? 50V Thick Film Resistor �100ppm/? �1% 0402 Chip Resistor - Surface Mount RoHS |https://www.lcsc.com/product-detail/C276273.html  |
|C7588889 |MTC201208-R47MT |0.47uH |MTC201208-R47MT | |6 |Ceaiya |10 |0.0623 |0.62 |0805 |10 |10 |3000 |3.8A 470nH �20% 4.8A 37m? Molded Inductor 0805 Fixed Inductors RoHS |https://www.lcsc.com/product-detail/C7588889.html |
|C47327420 |APS252012MR22F |0.22uH |APS252012MR22F | |4 |Coilank |20 |0.0275 |0.55 |1008 |20 |20 |3000 |8.6A 220nH �20% 14m? 10A 1008 Fixed Inductors RoHS |https://www.lcsc.com/product-detail/C47327420.html|
|C5832378 |FTC322512SR22MBCA |0.22uF |FTC322512SR22MBCA | |3 |cjiang |5 |0.2317 |1.16 |1210 |5 |5 |3000 |9.2A 220nH �20% 6.6m? 11.5A 1210 Fixed Inductors RoHS |https://www.lcsc.com/product-detail/C5832378.html |
|C39676082 |FTC404030S3R3MGCA |FTC404030S3R3MGCA |FTC404030S3R3MGCA | |2 |cjiang |5 |0.2586 |1.29 |SMD,4.1x4.1mm |5 |5 |2000 |5.3A 3.3uH �20% 8.5A 35m? SMD,4.1x4.1mm Fixed Inductors RoHS |https://www.lcsc.com/product-detail/C39676082.html|
|C88984 |BLM18PG330SN1D |33? 100MHz 0603 3A |BLM18PG330SN1D | |1 |muRata |50 |0.0250 |1.25 |0603 |50 |50 |4000 |33?@100MHz 1 Line Ferrite Bead 0603 3A 25m? |https://www.lcsc.com/product-detail/C88984.html |
|C7423318 |FTC303020D2R2MBCA |2.2uH |FTC303020D2R2MBCA | |1 |cjiang |5 |0.4068 |2.03 |SMD,3x3mm |5 |5 |3000 |4.7A 2.2uH �20% 6A 37m? SMD,3x3mm Fixed Inductors RoHS |https://www.lcsc.com/product-detail/C7423318.html |
|C85831 |BLM18KG121TN1D |BLM18KG121TN1D |BLM18KG121TN1D | |1 |muRata |50 |0.0233 |1.17 |0603 |50 |50 |4000 |120?@100MHz 1 Line Ferrite Bead 0603 3A 30m? |https://www.lcsc.com/product-detail/C85831.html |
|C239773 |ESD5341N-2/TR |ESD5341N-2_TR |ESD5341N-2_TR | |2 |WILLSEMI |20 |0.0382 |0.76 |DFN1006-2L |20 |20 |10000  |15VC Clamp 4A@8/20us Ipp TVS DIODE DFN1006-2L |https://www.lcsc.com/product-detail/C239773.html  |
|C153722 |ESD5304D-10/TR |ESD5304D-10_TR |ESD5304D-10_TR | |2 |WILLSEMI |10 |0.0725 |0.73 |DFN2510-10L |10 |10 |3000 |12VC Clamp 4A@8/20us Ipp TVS DIODE DFN2510-10L |https://www.lcsc.com/product-detail/C153722.html  |
|C916992 |B5819WS |B5819WS |B5819WS_C916992 | |2 |JSMSEMI |50 |0.0141 |0.71 |SOD-323 |50 |50 |3000 |Diode Independent 40V 1A Surface Mount SOD-323 |https://www.lcsc.com/product-detail/C916992.html  |
|C239604 |ESD5451N-2/TR |ESD5451N-2_TR |ESD5451N-2_TR | |2 |WILLSEMI |50 |0.0145 |0.73 |DFN1006-2L |50 |50 |10000  |10VC Clamp 8A@8/20us Ipp TVS DIODE DFN1006-2L |https://www.lcsc.com/product-detail/C239604.html  |
|C916992 |B5819WS |B5819WS_C916992 |B5819WS_C916992 | |2 |JSMSEMI |50 |0.0141 |0.71 |SOD-323 |50 |50 |3000 |Diode Independent 40V 1A Surface Mount SOD-323 |https://www.lcsc.com/product-detail/C916992.html  |
|C3020456 |GRM188R60J226KEA0D |22uF 6.3V 0603 |GRM188R60J226KEA0D | |21 |muRata |40 |0.0488 |1.95 |0603 |20 |20 |4000 |22uF �10% 6.3V Ceramic Capacitor X5R 0603 |https://www.lcsc.com/product-detail/C3020456.html |
|C5156489 |RK860-2 |RK860-2 |RK860-2 | |2 |Rockchip |2 |1.0102 |2.02 |WLCSP-20 |1 |1 |5000 |Buck Switching Regulator IC 0.5V~1.5V 1 Output 7A WLCSP-20 |https://www.lcsc.com/product-detail/C5156489.html |
|C116592 |TPS563201DDCR |TPS563201DDCR |TPS563201DDCR | |2 |TI |10 |0.0740 |0.74 |SOT-23-THIN-6 |10 |10 |3000 |580kHz Step-down type Adjustable 768mV~7V 3A SOT-23-THIN-6 Voltage Regulators - DC DC Switching Regulators RoHS|https://www.lcsc.com/product-detail/C116592.html  |
|C5378561 |FEXL0730A-3R3M |FEXL0730A-3R3M |FEXL0730A-3R3M | |2 |cjiang |2 |1.6625 |3.33 |SMD,7.8x7.6mm |1 |1 |1500 |10A 3.3uH �20% 15A 18m? SMD,7.8x7.6mm Fixed Inductors RoHS |https://www.lcsc.com/product-detail/C5378561.html |
|- | |RK3588 |BGA1088C65P34X34_2300X2300X204N | |1 |Rockchip |1 |- |- |BGA-1088 |1 |1 |60 |BGA-1088 Microcontrollers RoHS |https://www.lcsc.com/product-detail/C5156490.html |
|C783414 |RS0102YH8 |RS0102YH8 |RS0102YH8 | |1 |RUNIC |5 |0.3125 |1.56 |SOT-23-8 |5 |5 |3000 |24Mbps 1 2 SOT-23-8 Translators, Level Shifters RoHS |https://www.lcsc.com/product-detail/C783414.html  |
|C2878936 |TPS259804ONRGER |TPS259804ONRGER |TPS259804ONRGER | |1 |TI |1 |2.6352 |2.64 |VQFN-24-EP(4x4) |1 |1 |3000 |Surge Protection IC 2.7V~24V Surface Mount VQFN-24-EP(4x4) |https://www.lcsc.com/product-detail/C2878936.html |
|C3013605 |RTL8125BG-CG |RTL8125BG-CG |RTL8125BG-CG | |1 |REALTEK |1 |4.6371 |4.64 |QFN-48-EP(6x6) |1 |1 |490 |QFN-48-EP(6x6) Drivers, Receivers, Transceivers RoHS |https://www.lcsc.com/product-detail/C3013605.html |
|C7471904 | |HUSB238_xxxDD |WDFN-10-1EP_3x3mm_P0.5mm_EP1.8x2.5mm| |1 |- |1 |- |- |- |1 |1 | | |https://www.lcsc.com/product-detail/C7471904.html |
|C2803245 |KLMBG2JETD-B041 |KLMBG2JETD-B041 |KLMBG2JETD-B041 | |1 |SAMSUNG |1 |48.1814 |48.18 |FBGA-153 |1 |1 |112 |32GB eMMC 5.1 FBGA-153 Memory RoHS |https://www.lcsc.com/product-detail/C2803245.html |
|C2912103 |H9HCNNN8KUMLHR-NME |H9HCNNN8KUMLHR-NME |H9HCNNN8KUMLHR-NME | |1 |HYNIX |1 |24.8291 |24.83 |BGA-200(10x15) |1 |1 |240 |8Gbit 3.733GHz LPDDR4 SDRAM BGA-200(10x15) Memory RoHS |https://www.lcsc.com/product-detail/C2912103.html |
|C841386 |TPS56637RPAR |TPS56637RPAR |TPS56637RPAR | |1 |TI |1 |2.5308 |2.53 |VQFN-10-HR(3x3) |1 |1 |3000 |Buck Switching Regulator IC Adjustable 0.6V~13V 1 Output 6A VQFN-10-HR(3x3) |https://www.lcsc.com/product-detail/C841386.html  |
|C55266 |TPS2553DBVR |TPS2553DBVR |TPS2553DBVR | |1 |TI |5 |0.3927 |1.96 |SOT-23-6 |5 |5 |3000 |1 Active High 1.5A High Side Switch SOT-23-6 Power Distribution Switches, Load Drivers RoHS |https://www.lcsc.com/product-detail/C55266.html |
|- |RK806-1 |RK806-1 |QFN35P700X700X90-69N | |1 |Rockchip |1 |4.4364 |4.44 |QFN-68(7x7) |1 |1 |1000 |0.5V~3.4V QFN-68(7x7) Power Management - Specialized RoHS |https://www.lcsc.com/product-detail/C5156483.html |
|C512369 |RCLAMP0512TQTCT |RCLAMP0512TQTCT |RCLAMP0512TQTCT | |1 |SEMTECH |1 |0.4533 |0.45 |SMD-3P,1x0.6mm |1 |1 |3000 |8.5VC Clamp ESD DIODE 0402 |https://www.lcsc.com/product-detail/C512369.html  |
|C852832 |RT0402BRD0752K3L |52.3K 0402 |RT0402BRD0752K3L | |1 |YAGEO |50 |0.0259 |1.30 |0402 |50 |50 |10000  |62.5mW 52.3k? 50V Thin Film Resistor �25ppm/? �0.1% 0402 Chip Resistor - Surface Mount RoHS |https://www.lcsc.com/product-detail/C852832.html  |
|C22392669 |TPS56A37RPAR |TPS56A37RPAR |TPS56A37RPAR | |1 |TI |1 |2.0278 |2.03 |VQFN-HR-10(3x3) |1 |1 |3000 |Buck Switching Regulator IC Adjustable 0.6V~13V 1 Output 10A VQFN-HR-10(3x3) |https://www.lcsc.com/product-detail/C22392669.html|
|C699888 |SGM2576YN5G/TR |SGM2576YN5G_TR |SGM2576YN5G_TR | |1 |SGMICRO |1 |0.4069 |0.41 |SOT-23-5 |1 |1 |3000 |1 2.5A Active High Load Switch SOT-23-5 Power Distribution Switches, Load Drivers RoHS |https://www.lcsc.com/product-detail/C699888.html  |
|C78988 |SY8089AAAC |SY8089AAAC |SY8089AAAC | |1 |Silergy |5 |0.1510 |0.76 |SOT-23-5 |5 |5 |3000 |1MHz Step-down type Adjustable 2A SOT-23-5 Voltage Regulators - DC DC Switching Regulators RoHS |https://www.lcsc.com/product-detail/C78988.html |
|C5156487 |RK860-3 |RK860-3 |RK860-3 | |1 |Rockchip |1 |0.9138 |0.91 |WLCSP-20 |1 |1 |5000 |Buck Switching Regulator IC Adjustable 0.5V~1.5V 1 Output 7A WLCSP-20 |https://www.lcsc.com/product-detail/C5156487.html |
|C155754 |HYM8563S |HYM8563S |HYM8563S | |1 |Haoyu Microelectronics |0 |- |- |MSOP-8 |1 |1 |3000 |Built-in Yes MSOP-8 Real Time Clocks RoHS |https://www.lcsc.com/product-detail/C155754.html  |
|C5362614 |W25Q256JWPIQ |W25Q256JWPIQ |W25Q256JWPIQ | |1 |Winbond |1 |7.3170 |7.32 |WSON-8(5x6) |1 |1 |5000 |FLASH - NOR Memory IC 256Mbit SPI 133MHz WSON-8(5x6) |https://www.lcsc.com/product-detail/C5362614.html |
|C2965580 |XL7EL89CKI-111YLC-24M |XL7EL89CKI-111YLC-24M |XL7EL89CKI-111YLC-24M | |1 |YXC Crystal Oscillators  |5 |0.0817 |0.41 |SMD2016-4P |5 |5 |3000 |Crystal 24MHz �10ppm 8pF SMD2016-4P |https://www.lcsc.com/product-detail/C2965580.html |
|C97606 |SC-32S32.768kHz20PPM12.5pF |32.768kHz 12.5pF |SC-32S32_768kHz20PPM12_5pF | |1 |Seiko |5 |0.2206 |1.10 |SMD3215-2P |5 |5 |3000 |Crystal 32.768kHz �20ppm 12.5pF SMD3215-2P |https://www.lcsc.com/product-detail/C97606.html |
|C5444544 |XL2EL89COI-111YLC-25M |XL2EL89COI-111YLC-25M |XL2EL89COI-111YLC-25M | |1 |YXC Crystal Oscillators  |5 |0.0743 |0.37 |SMD3225-4P |5 |5 |3000 |Crystal 25MHz �10ppm 12pF SMD3225-4P |https://www.lcsc.com/product-detail/C5444544.html |
|C393942 |TS24CA |TS24CA |TS24CA | |5 |SHOU HAN |20 |0.0240 |0.48 |SMD,4.6x1.8mm |20 |20 |3000 |Tactile Switch SPST 3.5mm 4.55mm x 1.8mm Surface Mount, Right Angle |https://www.lcsc.com/product-detail/C393942.html  |
|C158014 |B2B-XH-2(LF)(SN) |B2B-XH-2_LF_SN |B2B-XH-2_LF_SN | |1 |JST |5 |0.0876 |0.44 |Through Hole,P=2.5mm |5 |5 |1000 |Connector Header 2 position 2.5mm Pitch 3A Through Hole -25?~+85? |https://www.lcsc.com/product-detail/C158014.html  |
|C2977809 |2199230-4 |2199230-4_C2977809 |2199230-4_C2977809 | |1 |TE Connectivity |1 |1.9969 |2.00 |SMD,P=0.5mm,Surface Mount,Right Angle|1 |1 |1000 |67 Position 0.5mm Pitch Gold Surface Mount, Right Angle |https://www.lcsc.com/product-detail/C2977809.html |
|C7425334 |HDMI-GD-121PWB |HDMI-GD-121PWB |HDMI-GD-121PWB | |1 |HDGC |1 |0.6957 |0.70 |Through Hole |1 |1 |1000 |HDMI-D Receptacle Connector 19 Position Through Hole, Right Angle |https://www.lcsc.com/product-detail/C7425334.html |
|C167139 |WPM3407-3/TR |WPM3407-3_TR |WPM3407-3_TR | |1 |WILLSEMI |5 |0.1281 |0.64 |SOT-23 |5 |5 |3000 |P-Channel 30V 4.4A 1.4W Surface Mount SOT-23 |https://www.lcsc.com/product-detail/C167139.html  |
|C113315 |2SK3018T106 |2SK3018T106 |2SK3018T106 | |1 |ROHM |10 |0.0569 |0.57 |SOT-323 |10 |10 |3000 |N-Channel 30V 100mA 200mW Surface Mount SOT-323 |https://www.lcsc.com/product-detail/C113315.html  |
|C18221467 |S8050-J3Y |S8050-J3Y |S8050-J3Y_C18221467 | |1 |JSMSEMI |50 |0.0095 |0.48 |SOT-23 |50 |50 |3000 |Bipolar (BJT) Transistor NPN 25V 300mA 150MHz 300mW Surface Mount SOT-23 |https://www.lcsc.com/product-detail/C18221467.html|
|C18221467 |S8050-J3Y |S8050-J3Y_C18221467 |S8050-J3Y_C18221467 | |1 |JSMSEMI |50 |0.0095 |0.48 |SOT-23 |50 |50 |3000 |Bipolar (BJT) Transistor NPN 25V 300mA 150MHz 300mW Surface Mount SOT-23 |https://www.lcsc.com/product-detail/C18221467.html|
|C16072 |AO4407A |AO4407A |AO4407A | |1 |AOS |5 |0.2726 |1.36 |SOIC-8 |5 |5 |3000 |P-Channel 30V 12A 3.1W Surface Mount SOIC-8 |https://www.lcsc.com/product-detail/C16072.html |
|C5342434 |HC-TYPE-C-16P-FL6.65Q-5A-06|HC-TYPE-C-16P-FL6_65Q-5A-06 |HC-TYPE-C-16P-FL6_65Q-5A-06 | |1 |HCTL |1 |0.7683 |0.77 |Through Hole |1 |1 |350 |USB-C (USB TYPE-C) Receptacle Connector 16 Position Vertical, Flag |https://www.lcsc.com/product-detail/C5342434.html |
|C129018 |TYPE-C-31-M-04 |TYPE-C-31-M-04 |TYPE-C-31-M-04 | |1 |Korean Hroparts Elec |1 |0.6420 |0.64 |SMD |1 |1 |1000 |USB-C (USB TYPE-C) Receptacle Connector 24 Position Through Hole |https://www.lcsc.com/product-detail/C129018.html  |
|- | |JT4-1108HL |PULSE_JT4-1108HL | |1 |PULSE |1 |4.4352 |4.44 |Through Hole,Right Angle |1 |1 |50 |Jack Modular Connector RJ45 Through Hole, Right Angle Shielded |https://www.lcsc.com/product-detail/C455440.html  |

>> This project is only made for fun and has not be tested due to high production costs.
>> Non-critical features including a second ethernet port has not been added.
>> M.2 have not been implemented due to time constraints remains functional without.
>> Many M.2 wifi cards are avaliable, ensure that they are M.2 and keyed corrected. High performance options include ones such as https://asiarf.com/product/wi-fi-7-be3600-m-2-ap-module-aw7990-aed
---

*Initially inspired by Tomaž Zaman's 10G router.*

- BUILT SOLO BY CXD (03/04/2026 - 03/08/2026)
- MADE FOR HC FALLOUT 2026

Changelog MMDDYYYY:
09-09-2026: v1.3 PCB Fixes.  
09-10-2026: v2.0.0 housing fixes, add sliding lid for the housing and fix mounting holes.


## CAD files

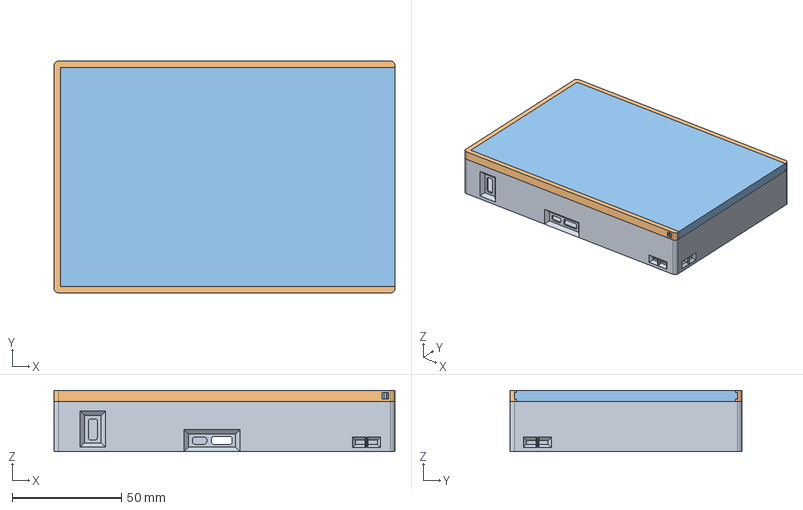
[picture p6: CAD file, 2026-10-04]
3D_Models/CXD_ROUTER_HOUSING_V2.0.0.step
156.0 x 106.0 x 28.0 mm

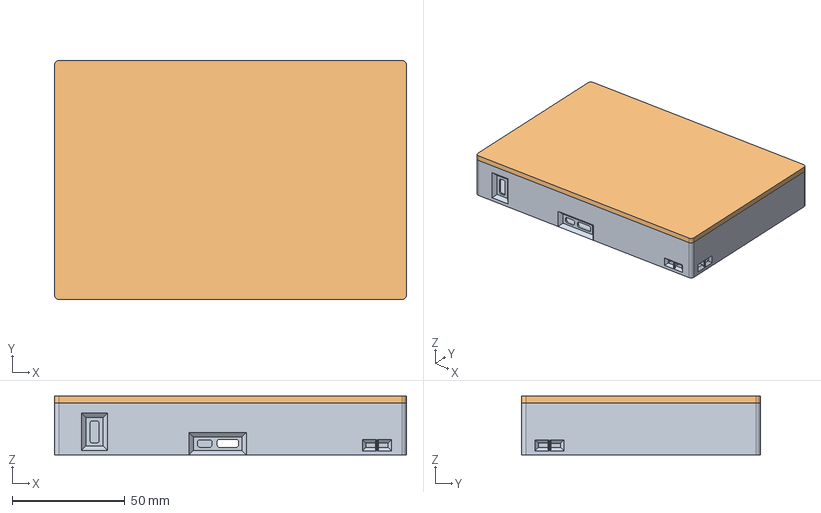
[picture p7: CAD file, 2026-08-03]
3D_Models/CXD_ROUTER.step
156.0 x 106.0 x 26.0 mm

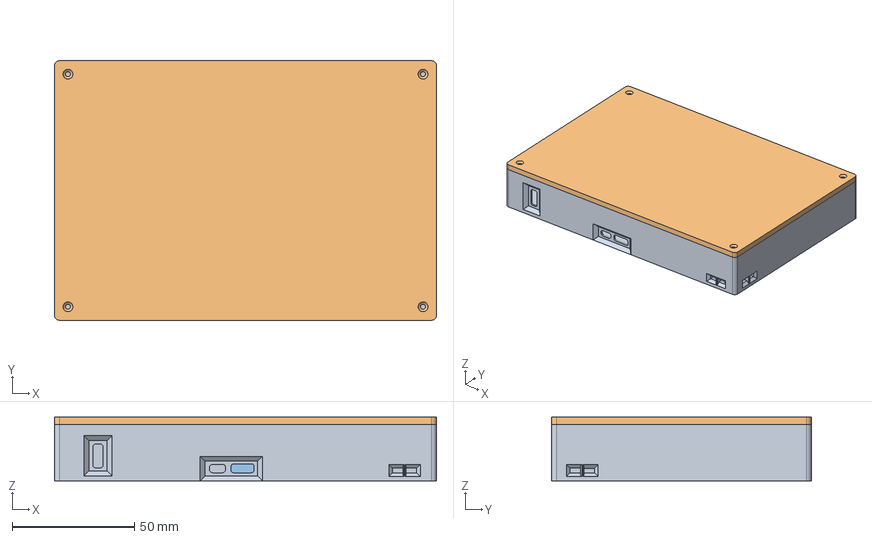
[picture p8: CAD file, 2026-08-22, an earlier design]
3D_Models/CXD_ROUTER_Housing_V1.1.step
156.0 x 106.0 x 26.0 mm

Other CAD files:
3D_Models/CXD_ROUTER.f3d
3D_Models/CXD_ROUTER_HOUSING_V2.0.0.stl
3D_Models/CXD_ROUTER_HOUSING_v2.0.0.f3d
3D_Models/CXD_ROUTER_Housing_V1.1.f3d

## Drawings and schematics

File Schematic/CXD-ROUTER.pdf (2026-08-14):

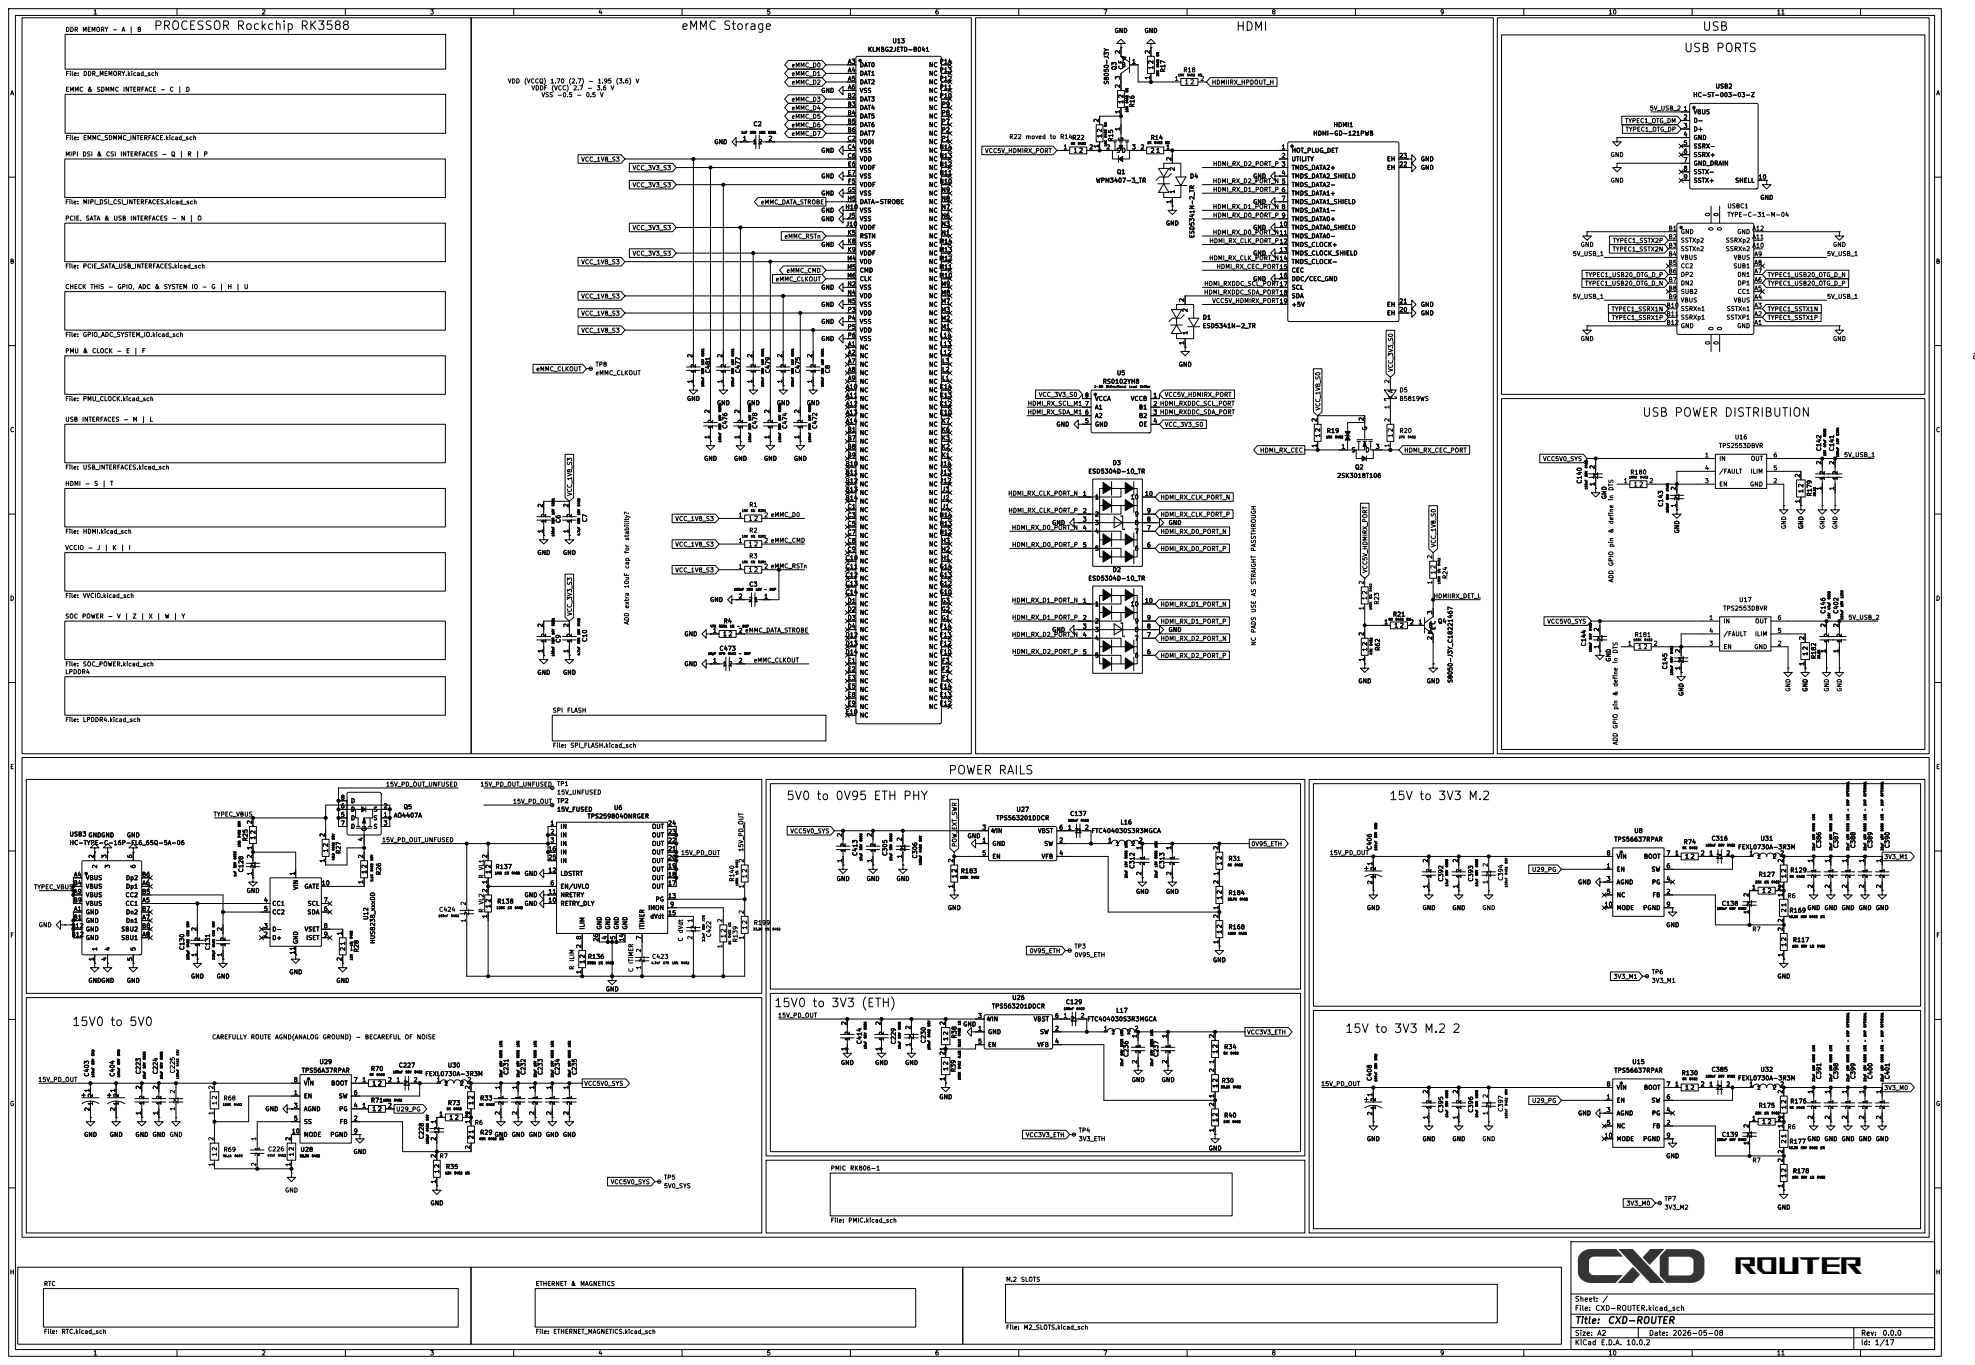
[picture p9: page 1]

U13 KLMBG2JETD-B041 NC A1 NC A2 DAT0 A3 DAT1 A4 DAT2 A5
VSS A6 NC A7 NC A8 NC A9 NC A10 NC A11 NC A12 NC A13 NC A14 NC B1

ESD5304D-10_TR NC A1 NC A2 DAT0 A3 DAT1 A4 DAT2 A5
DAT3 B2 DAT4 B3 DAT5 B4 DAT6 B5 DAT7 B6 NC B7 NC B8 NC B9 NC B10 NC B11 NC B12 NC B13 NC B14 NC C1

SHELL 10 USB2 HC-ST-003-03-Z GND

GND

VDDI C2 NC C3
VSS C4 NC C5
VDD C6 NC C7 NC C8 NC C9 NC C10 NC C11 NC C12 NC C13 NC C14 NC D1 NC D2 NC D3 NC D4 NC D12 NC D13 NC D14 NC E1 NC E2 NC E3 NC E5

File: EMMC_SDMMC_INTERFACE.kicad_sch MIPI DSI & CSI INTERFACES - Q | R | P

PCIE, SATA & USB INTERFACES - N | O

CHECK THIS - GPIO, ADC & SYSTEM IO - G | H | U

add anything else to trigger otg depending on connected device ID?

VCCIO - J | K | I File: VVCIO.kicad_sch HDMI - S | T File: HDMI.kicad_sch

R6 NC PADS USE AS STRAIGHT PASSTHROUGH

2 C400 22uF 10V 0805 10% - DNP OPTIONAL GND GND

5V0 to 0V95 ETH PHY VBST 6 U27 VBST 6 C137 2 C137 TPS563201DDCR TPS563201DDCR 100nF 0402 1 L16 L16 0V95_ETH | 15V to 3V3 M.2 2 C316 2 U31 2 C316 TPS56637RPAR TPS56637RPAR

2 2
1 1 | AO4407A S

2 GND GND USB3 HC-TYPE-C-16P-FL6_65Q-5A-06

2 C404 100uF 80V SMD GND GND GND

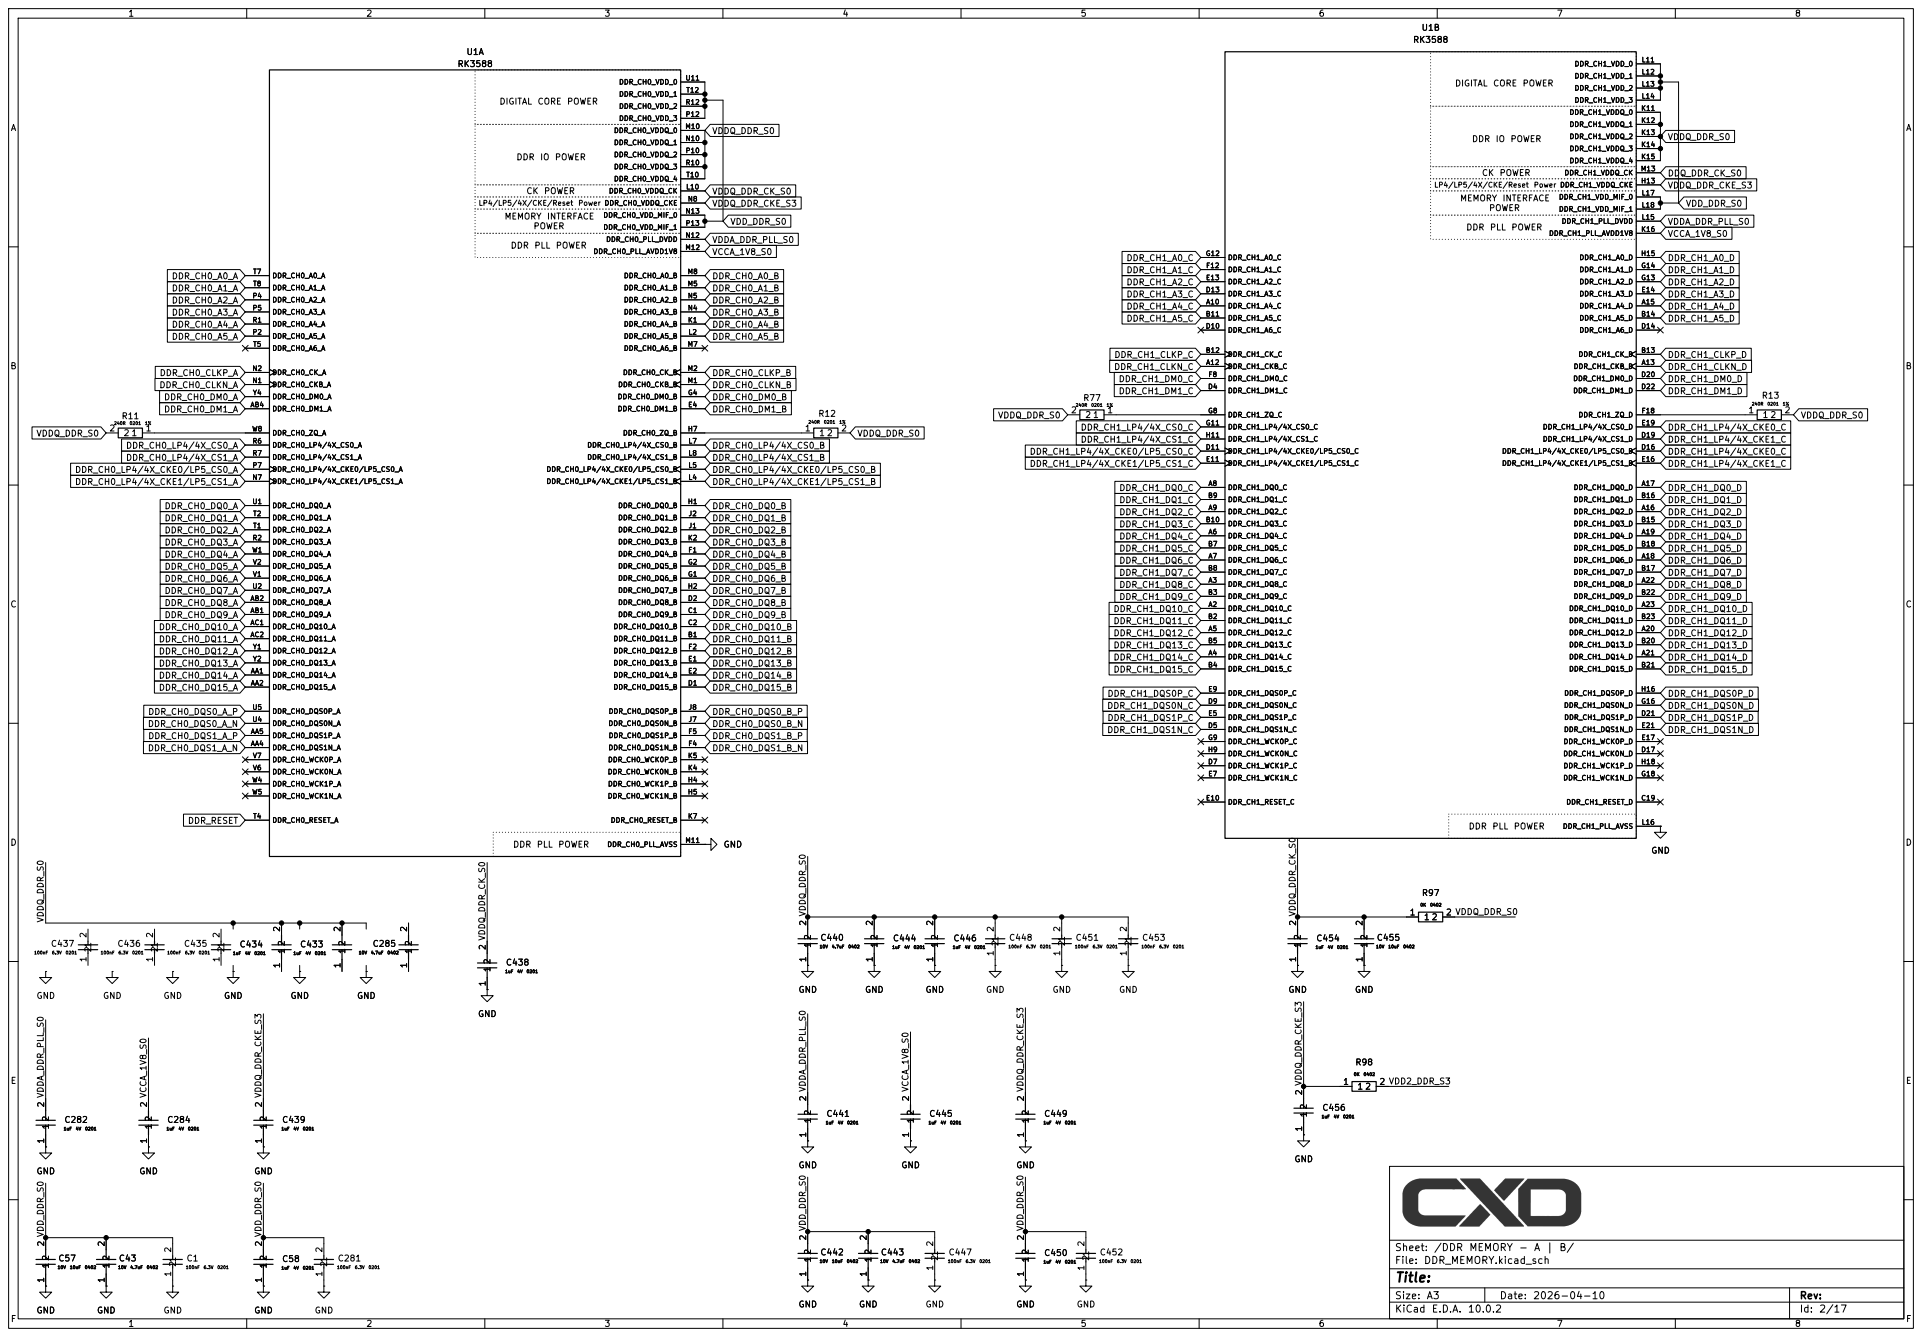
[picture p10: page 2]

LP4/LP5/4X/CKE/Reset Power DIGITAL CORE POWER

DDR IO POWER MEMORY INTERFACE POWER

DDR PLL POWER MEMORY INTERFACE POWER

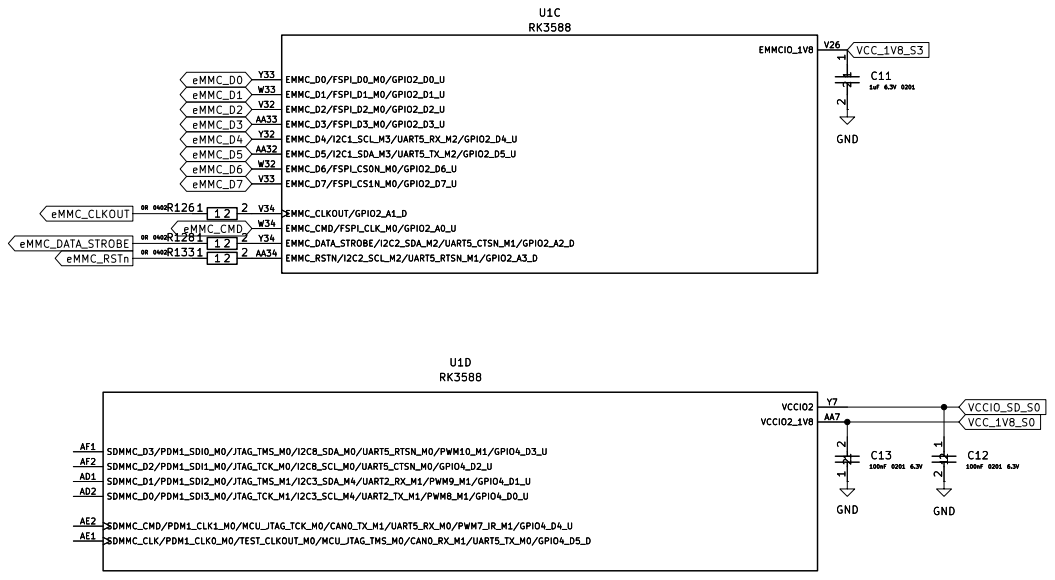
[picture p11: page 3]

Sheet: /EMMC & SDMMC INTERFACE - C | D/
File: EMMC_SDMMC_INTERFACE.kicad_sch

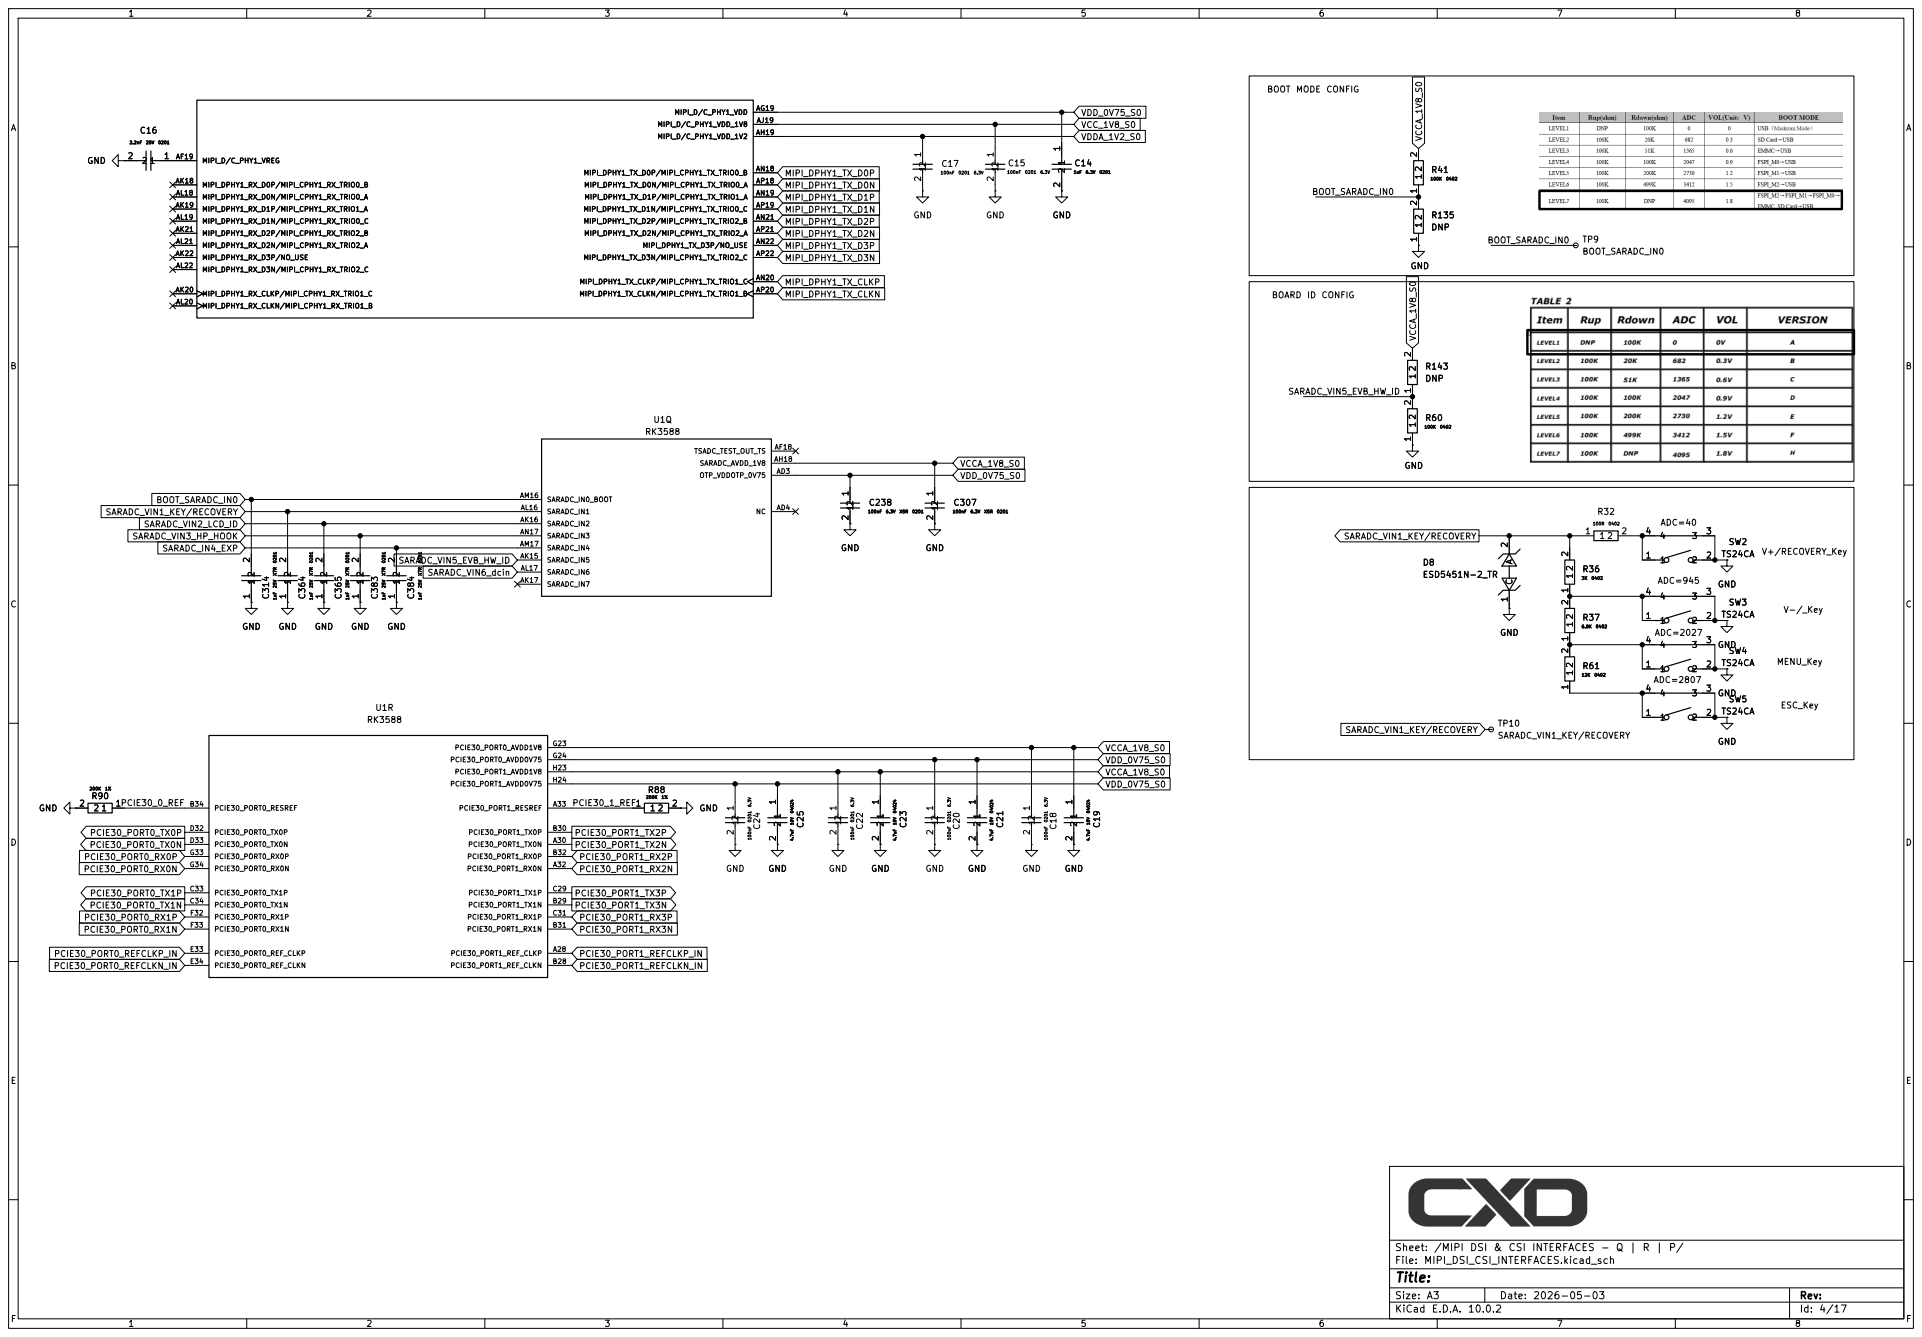
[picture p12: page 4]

SARADC_IN4 AM17
SARADC_IN5 AK15 SARADC_IN6 AL17 SARADC_IN7 AK17

Sheet: /MIPI DSI & CSI INTERFACES - Q | R | P/
File: MIPI_DSI_CSI_INTERFACES.kicad_sch

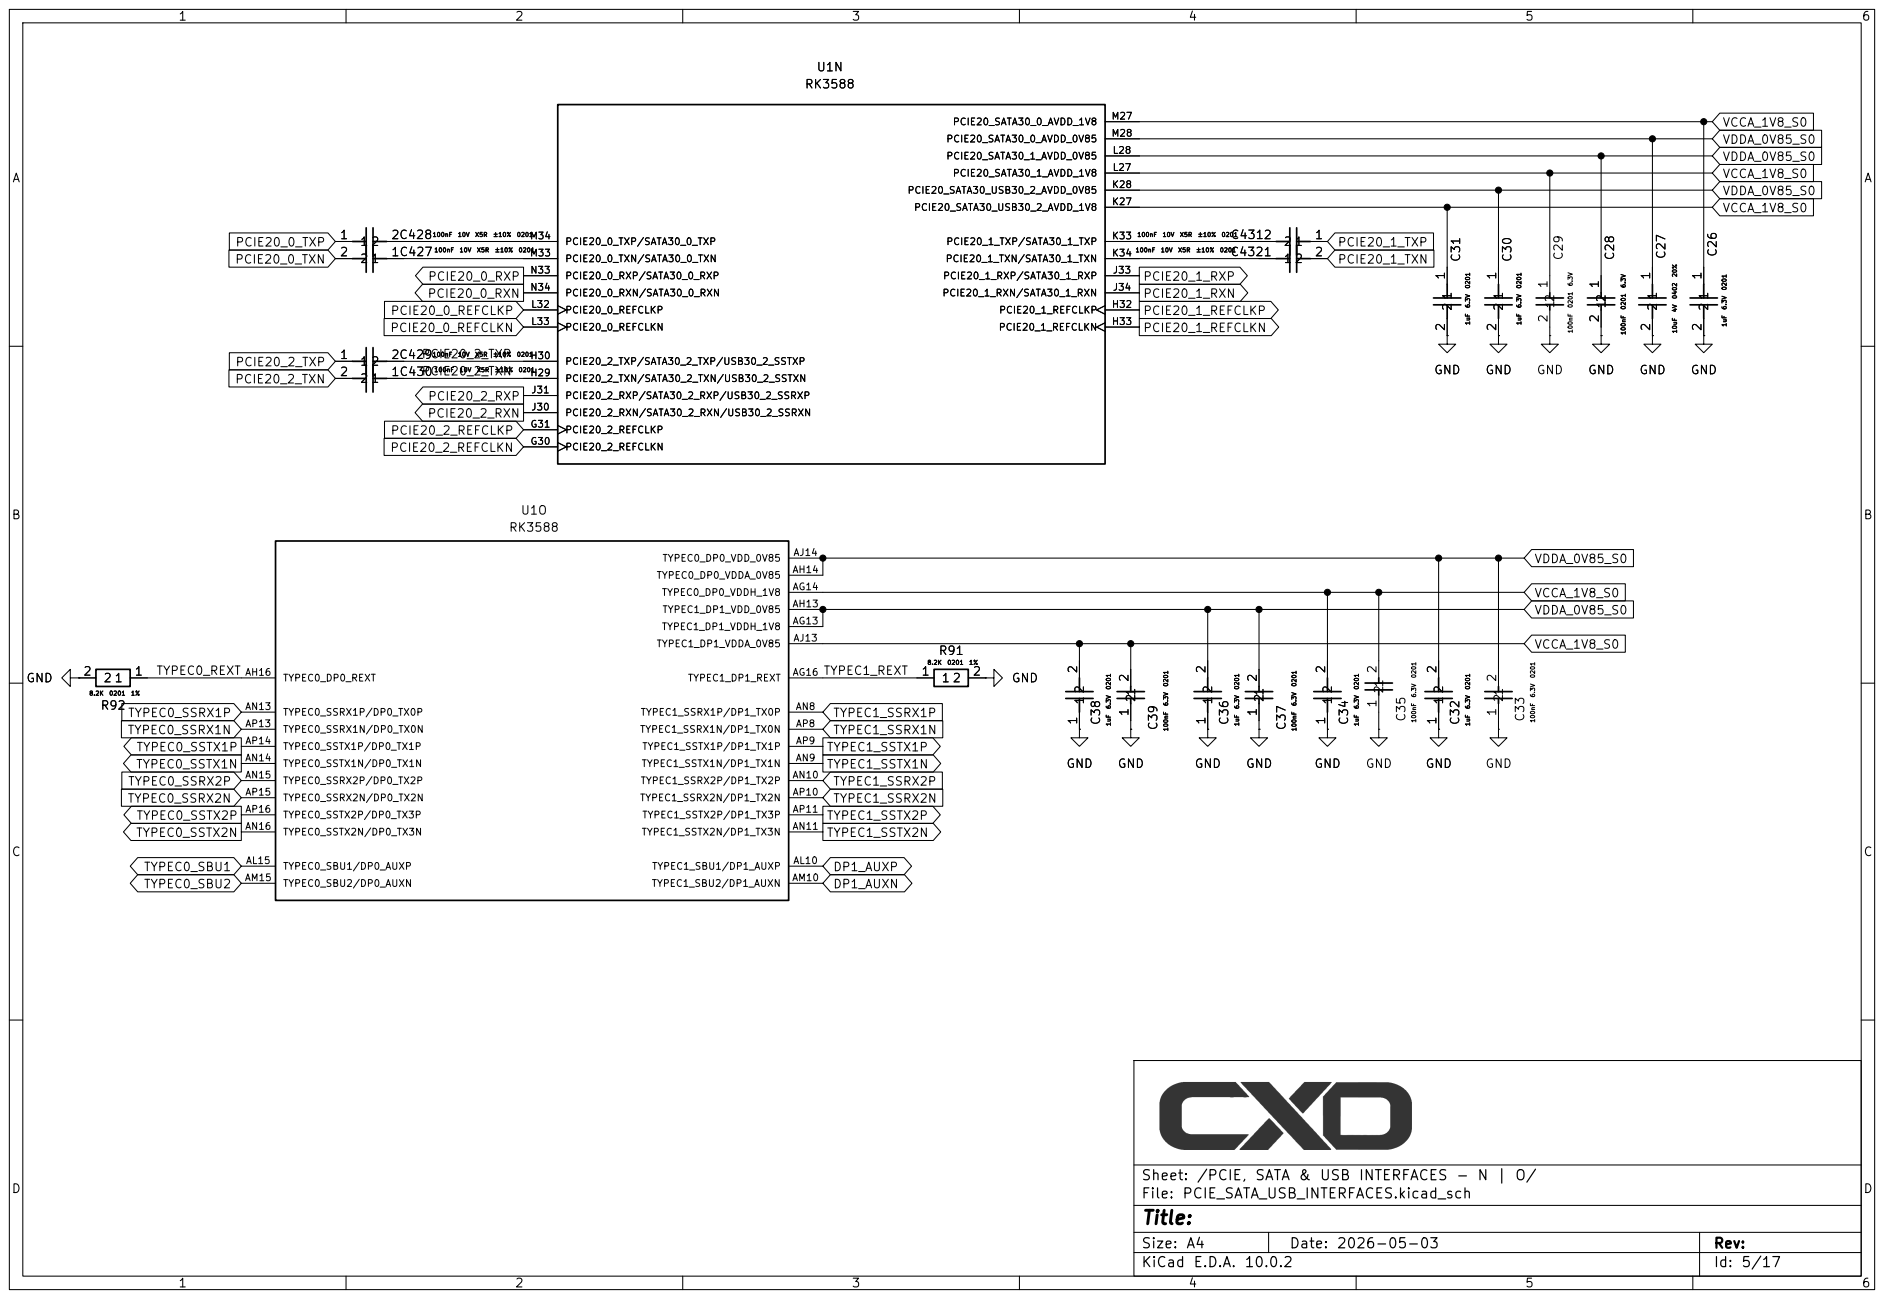
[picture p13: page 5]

Sheet: /PCIE, SATA & USB INTERFACES - N | O/
File: PCIE_SATA_USB_INTERFACES.kicad_sch
Title:

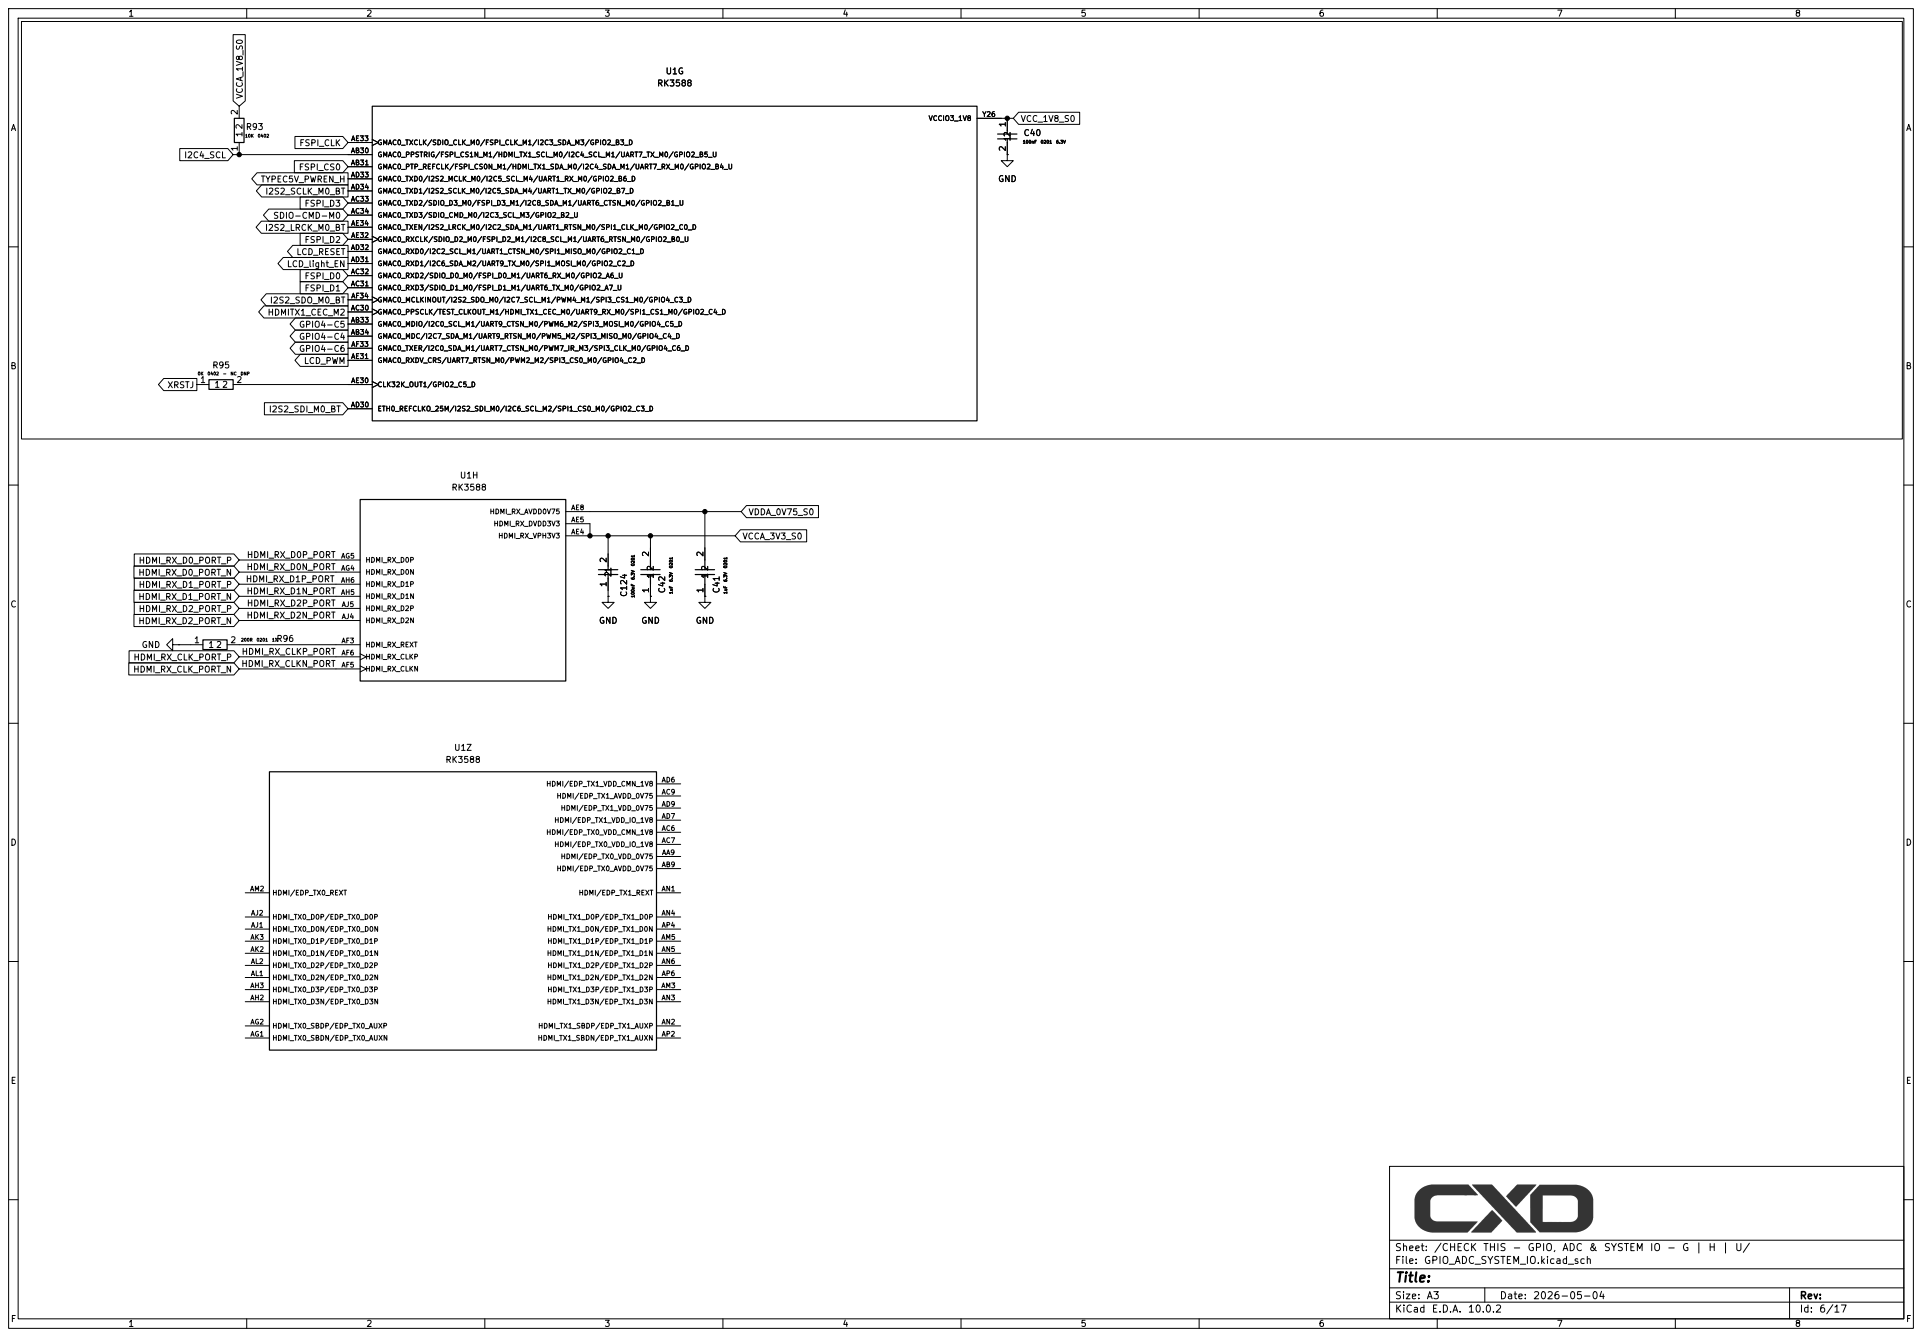
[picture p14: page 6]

Sheet: /CHECK THIS - GPIO, ADC & SYSTEM IO - G | H | U/
File: GPIO_ADC_SYSTEM_IO.kicad_sch

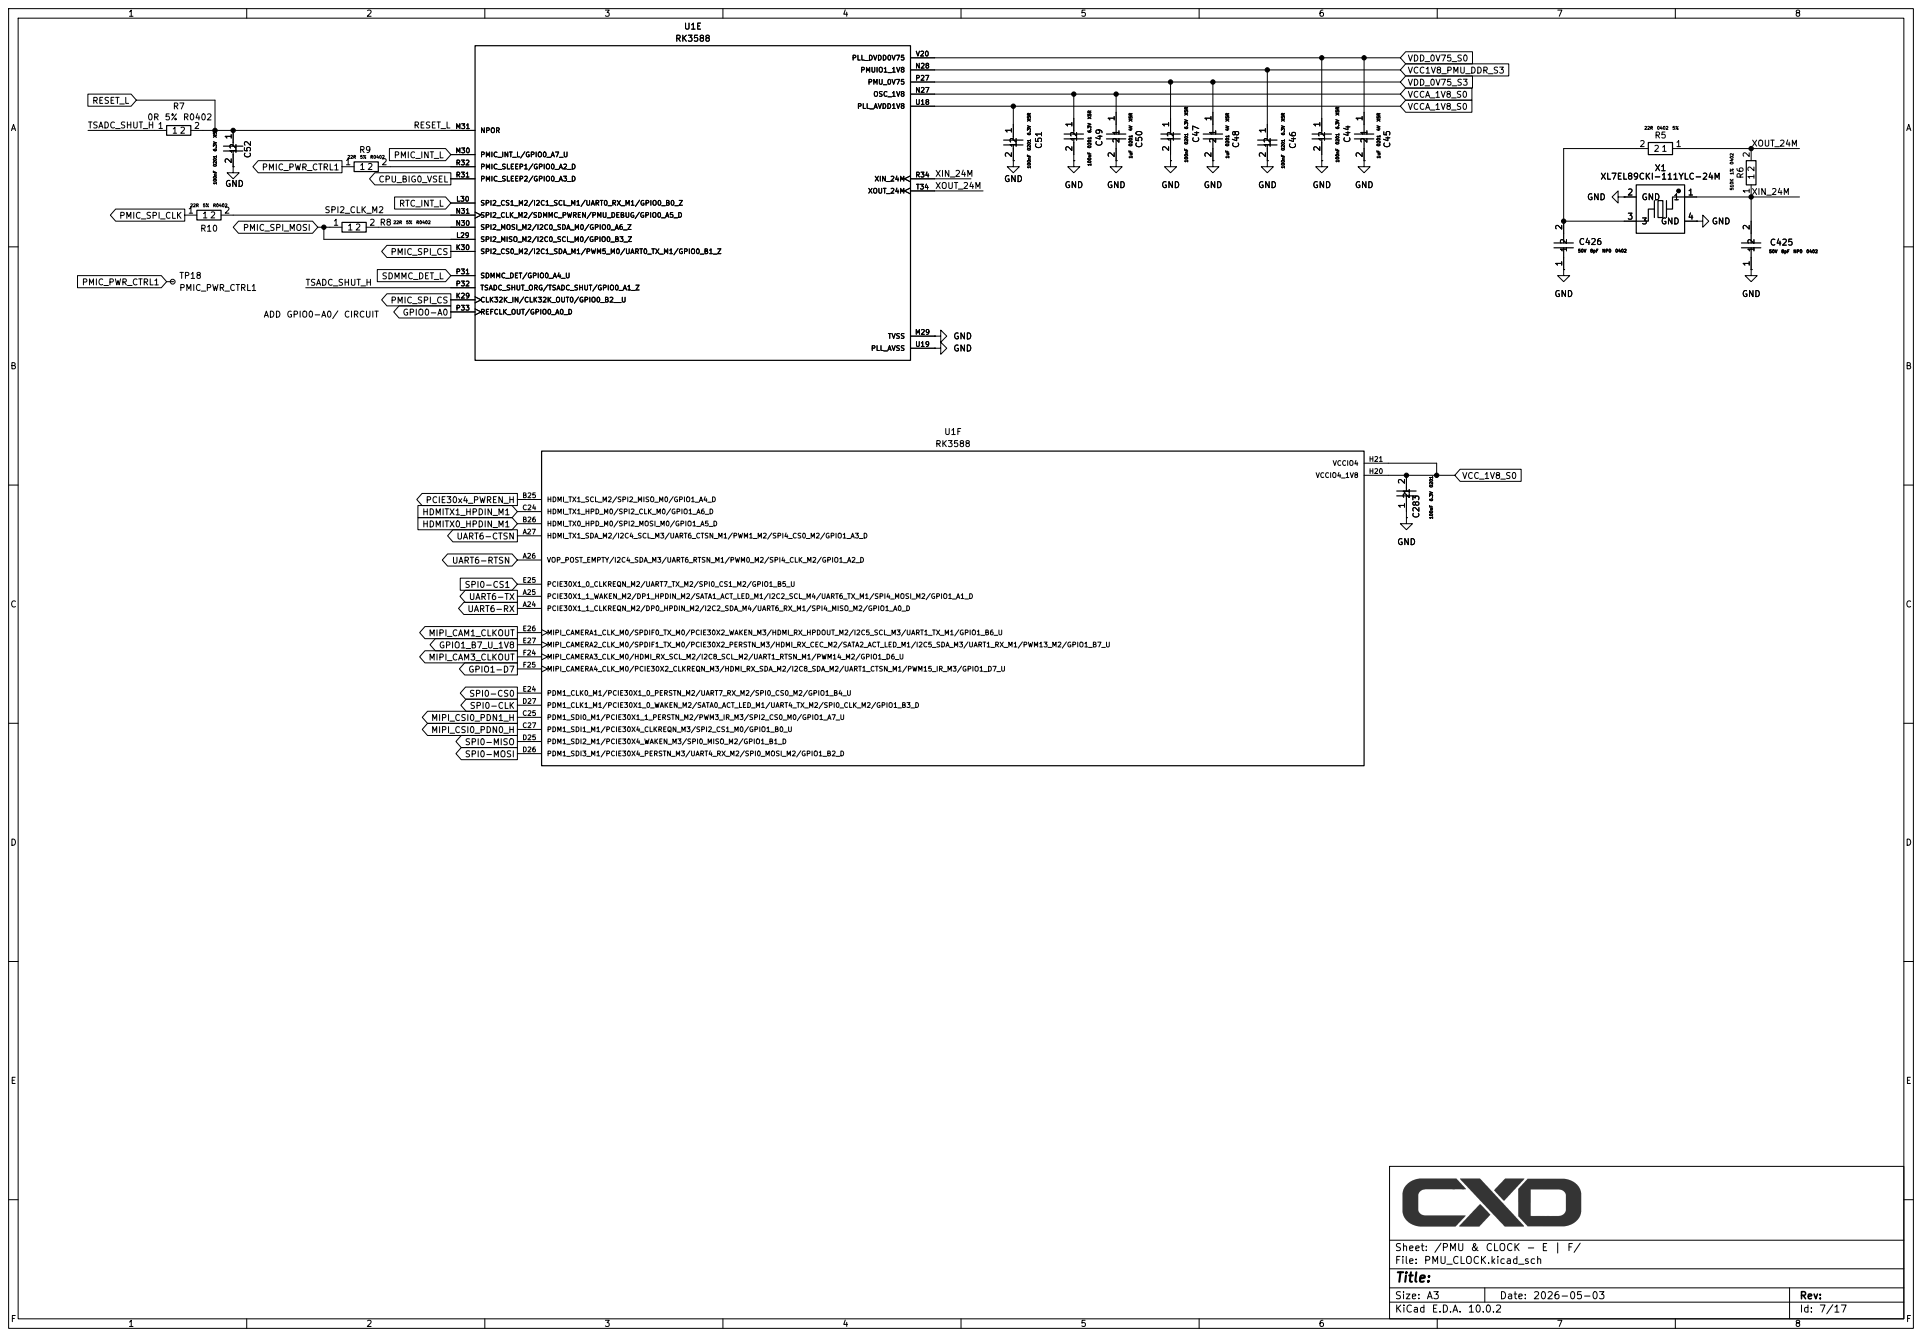
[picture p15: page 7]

2 | TSADC_SHUT_ORG/TSADC_SHUT/GPIO0_A1_Z P32 REFCLK_OUT/GPIO0_A0_D P33 PMIC_SLEEP2/GPIO0_A3_D R31 PMIC_SLEEP1/GPIO0_A2_D R32 TSADC_SHUT_ORG/TSADC_SHUT/GPIO0_A1_Z P32 REFCLK_OUT/GPIO0_A0_D P33 PMIC_SLEEP2/GPIO0_A3_D R31 PMIC_SLEEP1/GPIO0_A2_D R32 SPI2_CS1_M2/I2C1_SCL_M1/UART0_RX_M1/GPIO0_B0_Z L30 SPI2_CS1_M2/I2C1_SCL_M1/UART0_RX_M1/GPIO0_B0_Z L30

1 GND 2

2 | SPI2_MISO_M2/I2C0_SCL_M0/GPIO0_B3_Z L29

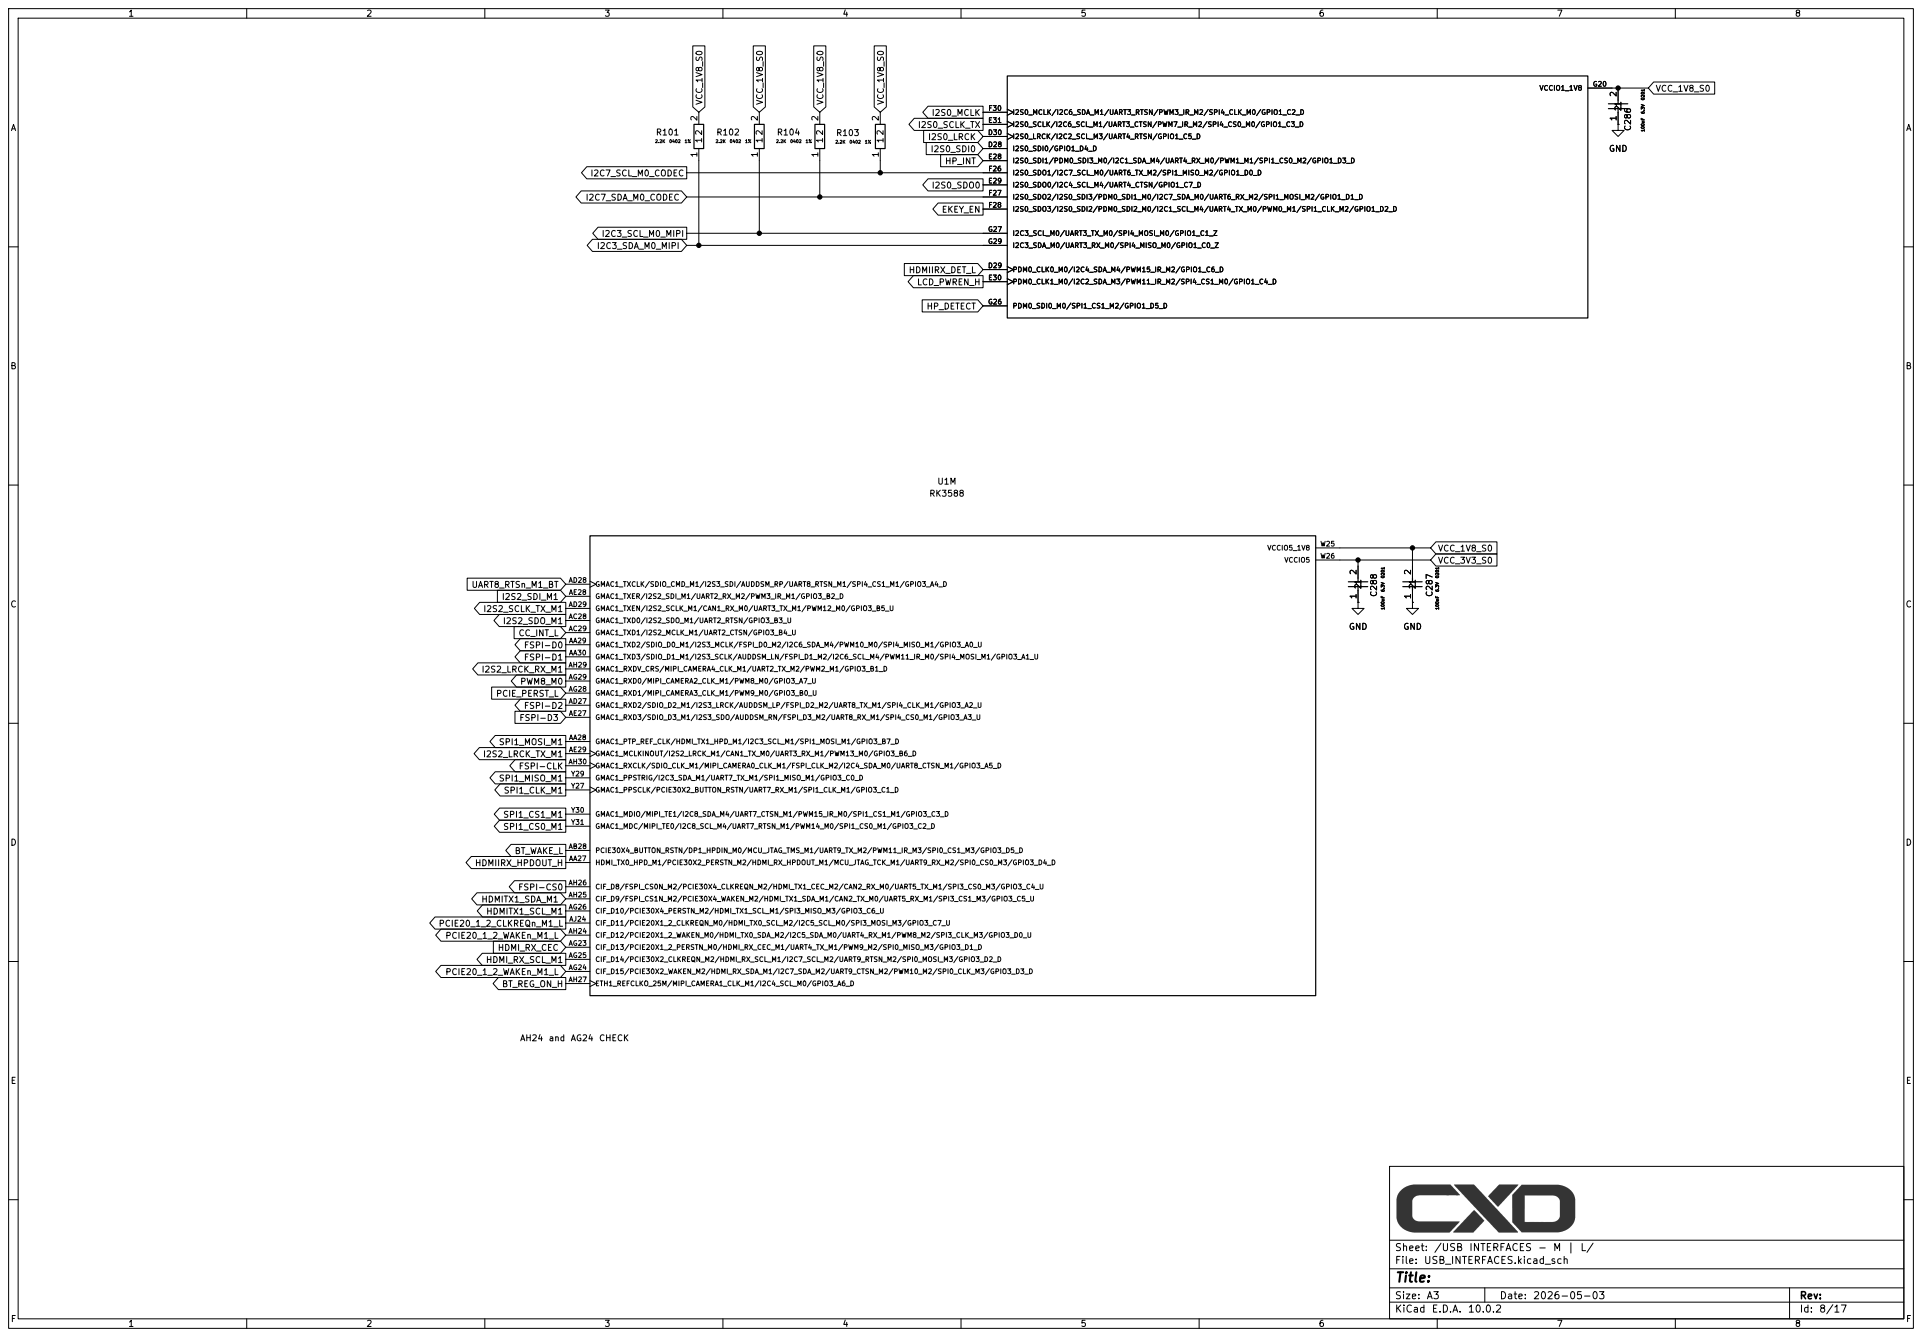
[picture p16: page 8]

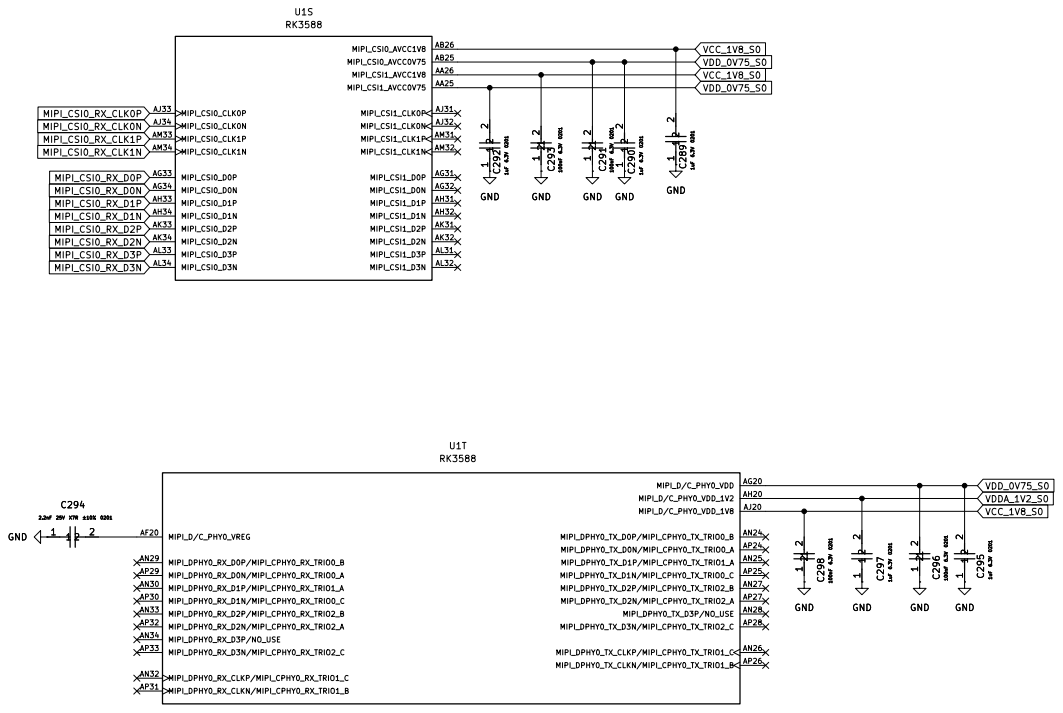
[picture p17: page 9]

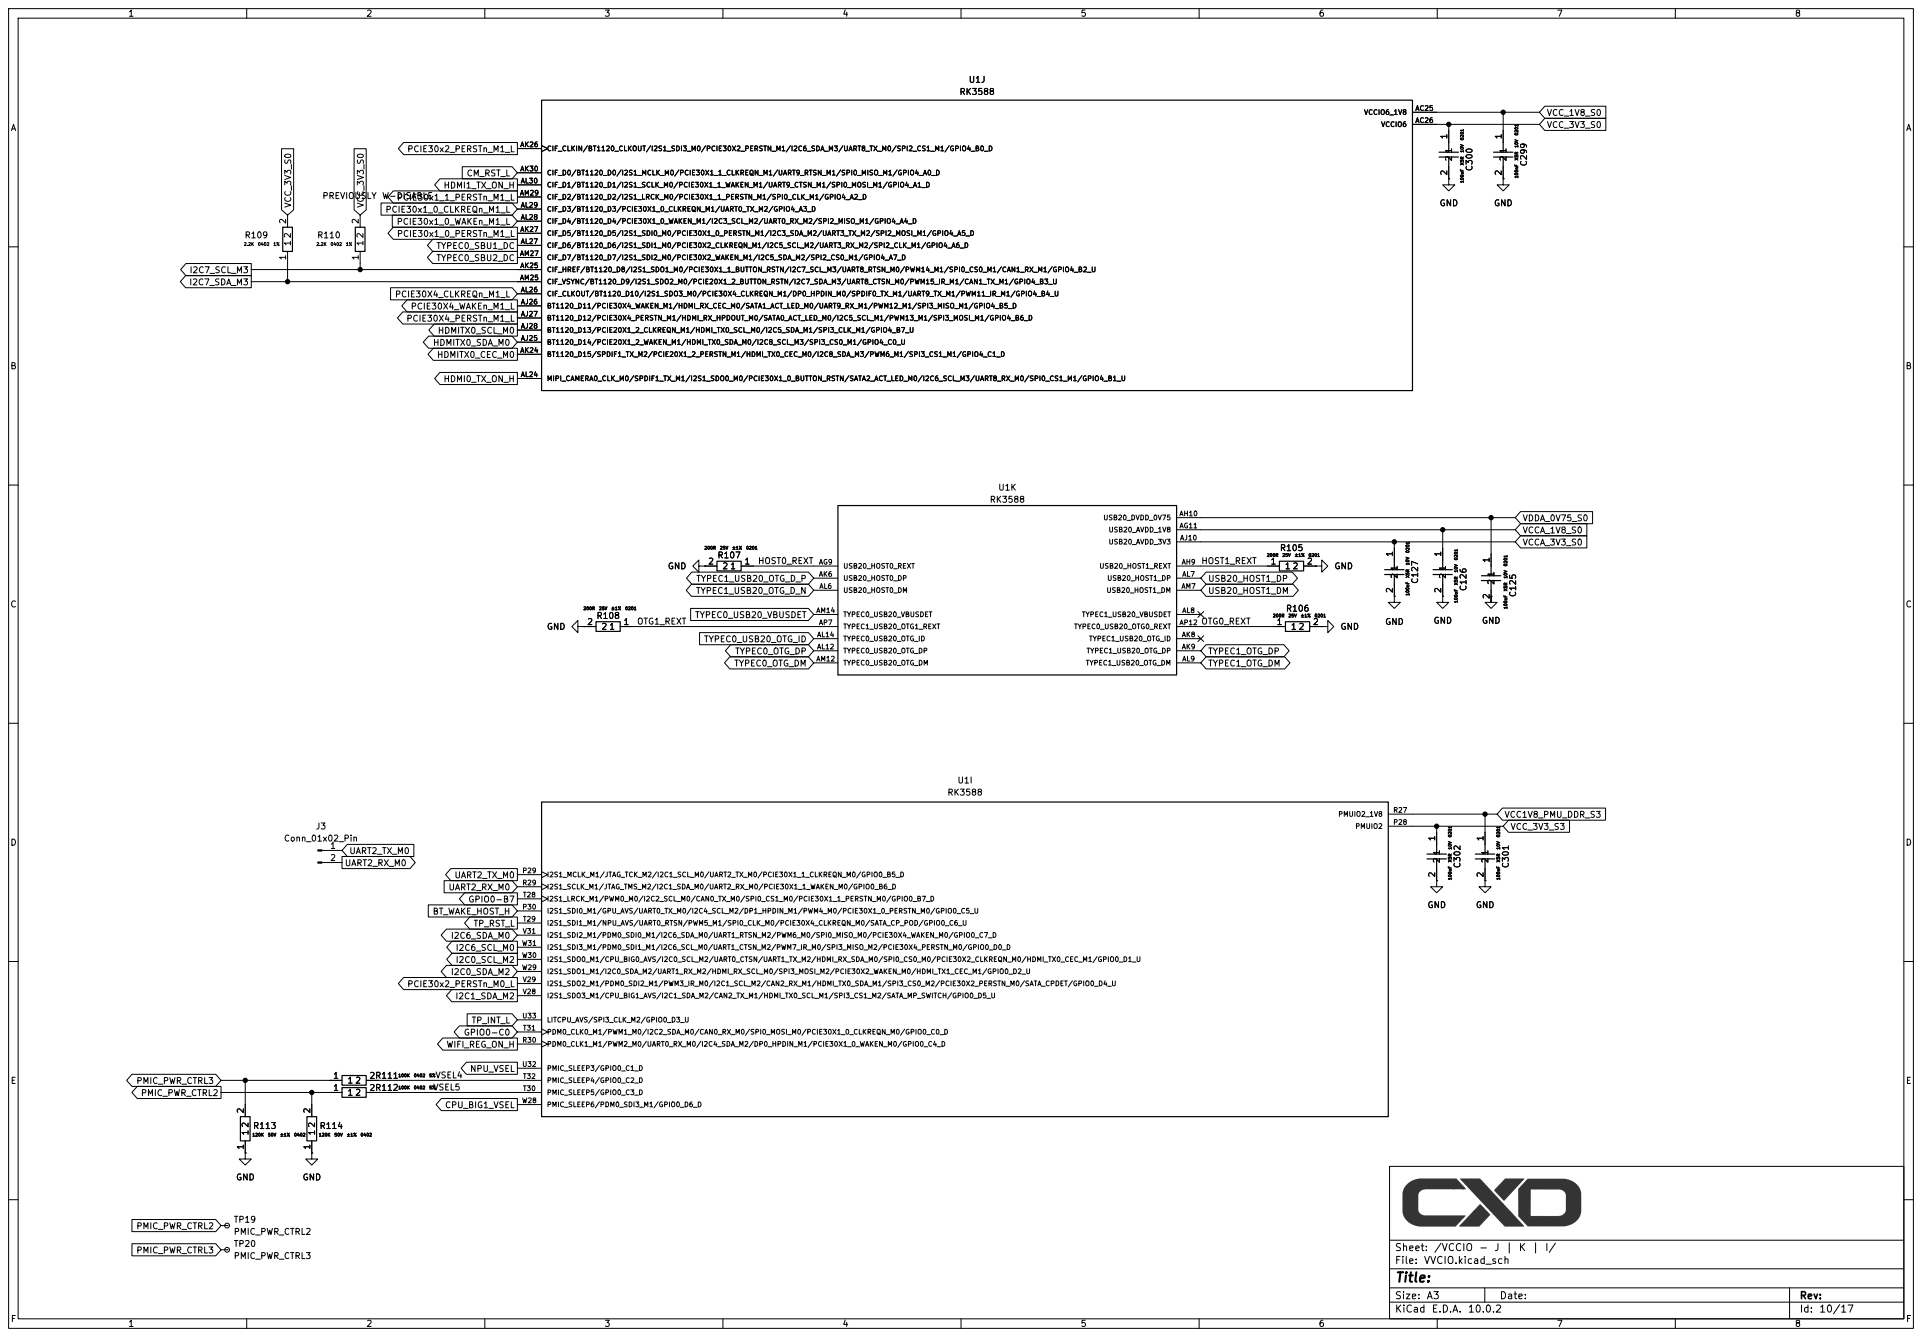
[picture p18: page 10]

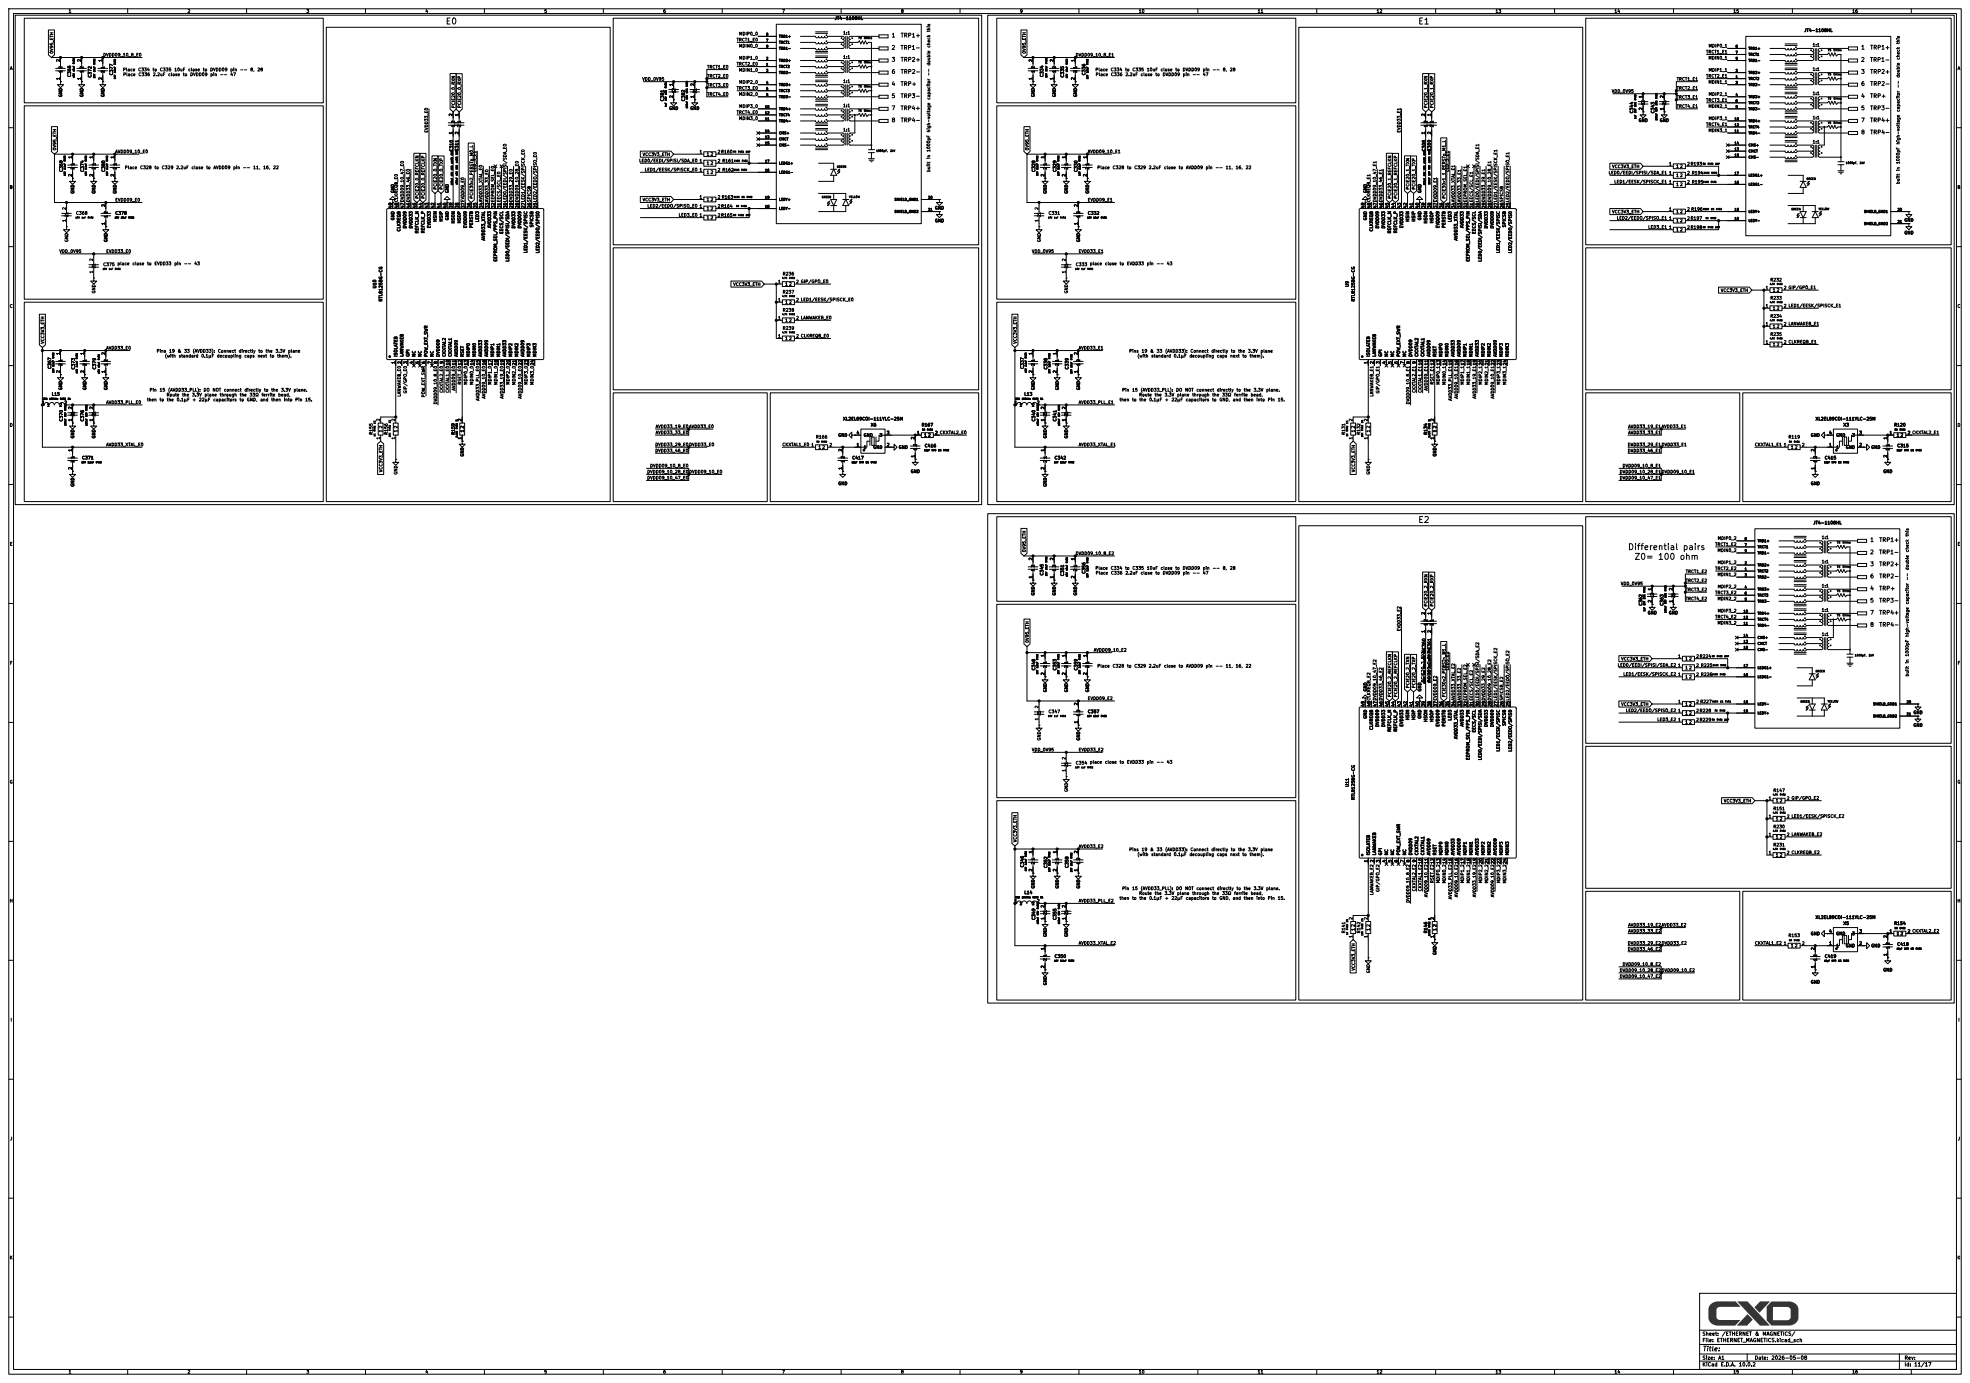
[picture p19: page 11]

Place C328 to C329 2.2uF close to AVDD09 pin -- 11, 16, 22 Place C334 to C335 10uF close to DVDD09 pin -- 8, 28

2 GND GND GND GND

2 C369 16V 2.2uF 0402 GND GND GND GND GND ISOLATEB

2 GND GND GND GND U10 RTL8125BG-CG ISOLATEB

2 GND GND U9 RTL8125BG-CG ISOLATEB

place close to EVDD33 pin -- 43 Place C328 to C329 2.2uF close to AVDD09 pin -- 11, 16, 22

9 CKXTAL1 10 AVDD09 11 RSET 12 MDIP0 13 MDIN0 14 AVDD33 15 AVDD09 16 MDIP1 17 MDIN1 18 AVDD33 19 MDIP2 20 MDIN2 21 AVDD09 22 MDIP3 23 MDIN3 24 LED2/EEDO/SPIS0 25 SPICSB 26 LED1/EESK/SPISC 27 DVDD09 28 DVDD33 29 LED0/EEDI/SPISI/SDA 30 EECS/SCL 31 EEPROM_SEL/PPS_PIN 32 AVDD33 33 AVDD33_XTAL 34 LED3 35 PERSTB 36 EVDD09 37 HSOP 38 HSON 39 GND 40 HSIP 41 HSIN 42 EVDD33 43 REFCLK_P 44 REFCLK_N 45 DVDD33 46 DVDD09 47 CLKREQB 48 GND 49 U10 RTL8125BG-CG GND 1

9 CKXTAL1 10 AVDD09 11 RSET 12 MDIP0 13 MDIN0 14 AVDD33 15 AVDD09 16 MDIP1 17 MDIN1 18 AVDD33 19 MDIP2 20 MDIN2 21 AVDD09 22 MDIP3 23 MDIN3 24 LED2/EEDO/SPIS0 25 SPICSB 26 LED1/EESK/SPISC 27 DVDD09 28 DVDD33 29 LED0/EEDI/SPISI/SDA 30 EECS/SCL 31 EEPROM_SEL/PPS_PIN 32 AVDD33 33 AVDD33_XTAL 34 LED3 35 PERSTB 36 EVDD09 37 HSOP 38 HSON 39 GND 40 HSIP 41 HSIN 42 EVDD33 43 REFCLK_P 44 REFCLK_N 45 DVDD33 46 DVDD09 47 CLKREQB 48 GND 49 GND R159 2.49K 0402 % 1

9 CKXTAL1 10 AVDD09 11 RSET 12 MDIP0 13 MDIN0 14 AVDD33 15 AVDD09 16 MDIP1 17 MDIN1 18 AVDD33 19 MDIP2 20 MDIN2 21 AVDD09 22 MDIP3 23 MDIN3 24 LED2/EEDO/SPIS0 25 SPICSB 26 LED1/EESK/SPISC 27 DVDD09 28 DVDD33 29 LED0/EEDI/SPISI/SDA 30 EECS/SCL 31 EEPROM_SEL/PPS_PIN 32 AVDD33 33 AVDD33_XTAL 34 LED3 35 PERSTB 36 EVDD09 37 HSOP 38 HSON 39 GND 40 HSIP 41 HSIN 42 EVDD33 43 REFCLK_P 44 REFCLK_N 45 DVDD33 46 DVDD09 47 CLKREQB 48 GND 49 U9 RTL8125BG-CG

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

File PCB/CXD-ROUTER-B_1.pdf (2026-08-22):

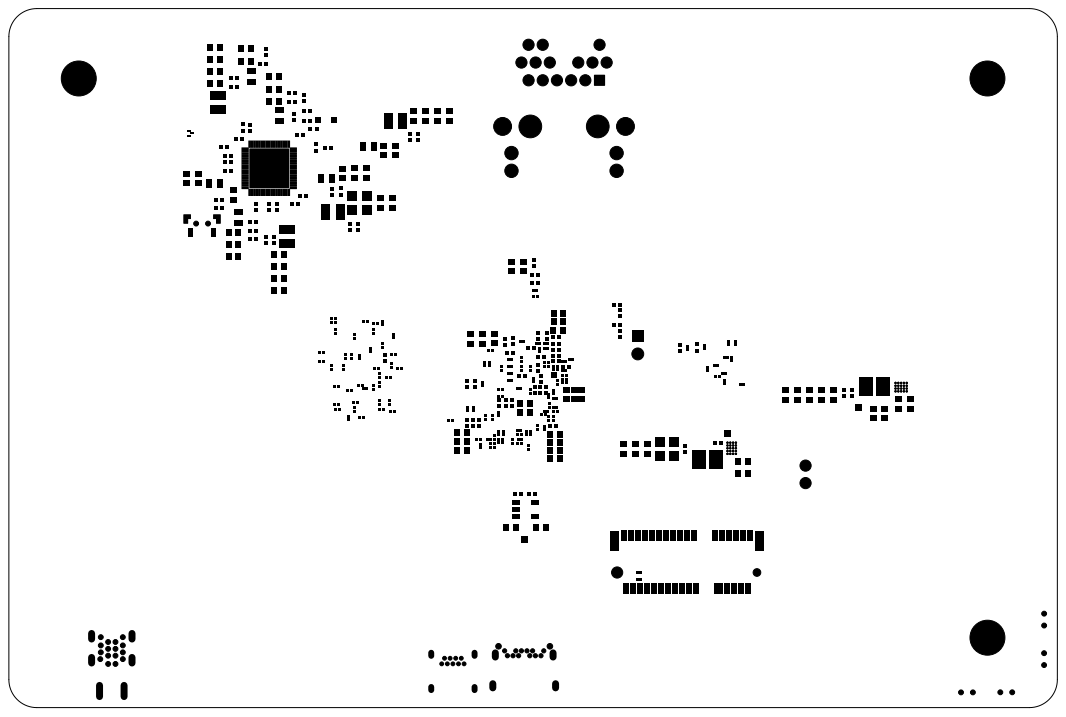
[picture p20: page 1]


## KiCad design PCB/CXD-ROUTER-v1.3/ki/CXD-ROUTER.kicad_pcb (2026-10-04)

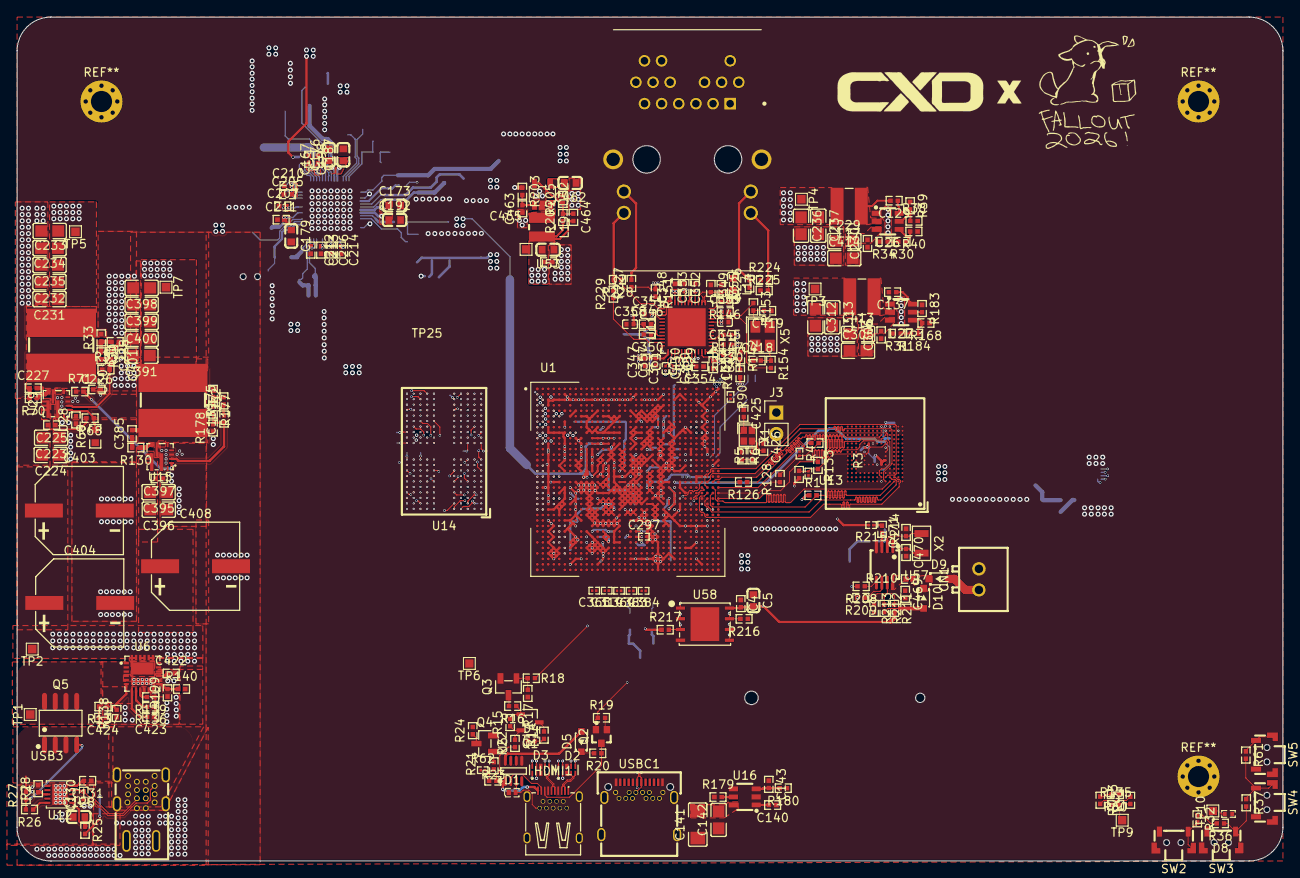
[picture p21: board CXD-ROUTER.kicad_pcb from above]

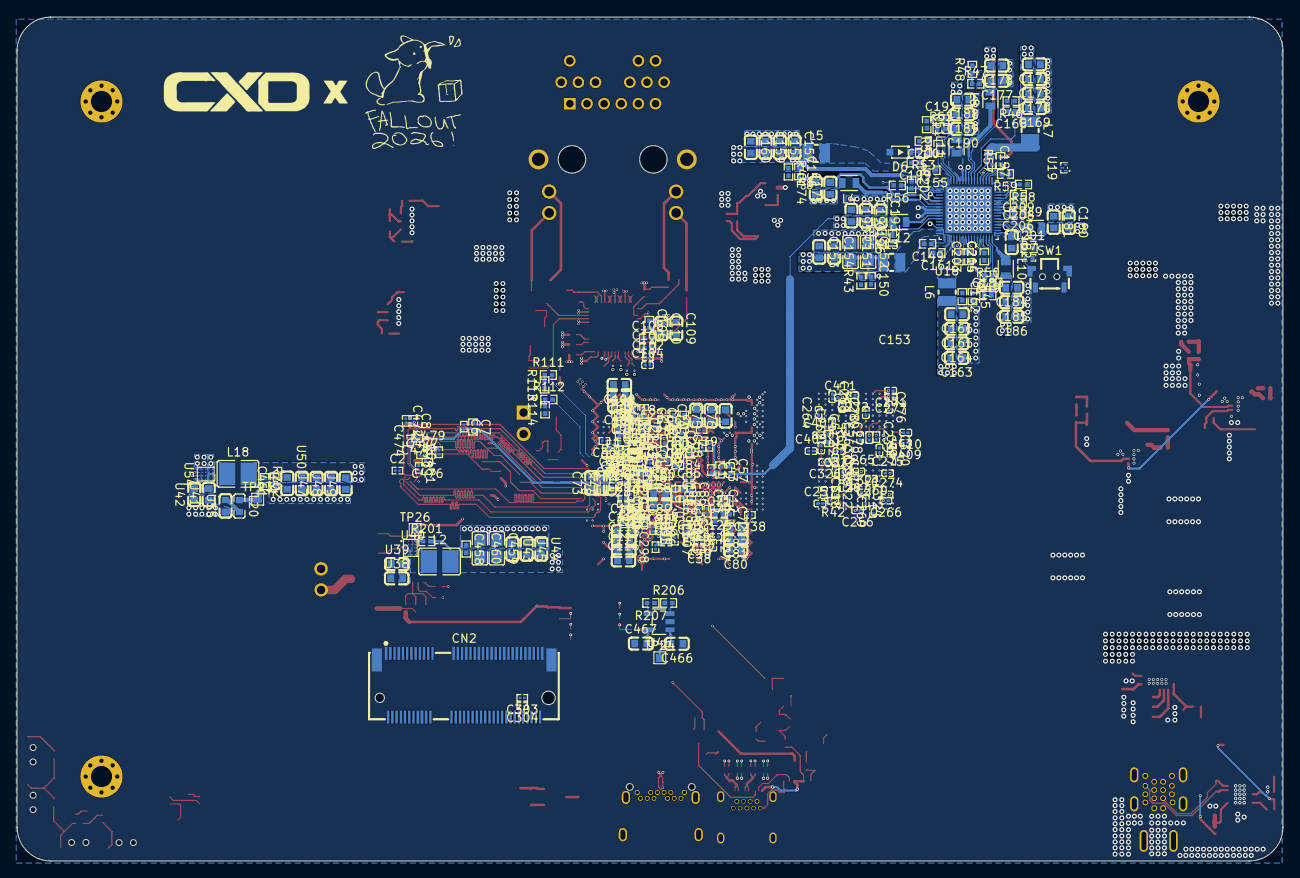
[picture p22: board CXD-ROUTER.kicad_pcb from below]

Board: 10 copper layers, 150.0 x 100.0 mm, 552 parts (301 on the bottom side), 311 nets.

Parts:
C1, C2, C3, C6, C8, C11, C12, C13, C14, C15, C17, C18, C20, C22, C24, C26, C28, C29, C30, C32, C33, C34, C35, C36, C37, C38, C39, C46, C47, C48, C49, C50, C51, C58, C63, C64, C70, C102, C112, C238, C281, C282, C286, C287, C288, C289, C290, C291, C292, C293, C295, C296, C297, C298, C303, C304, C307, C314, C364, C365, C383, C384, C439, C472, C474, C475, C476, C477, C478, C479, C481: -; RC0201FR-0749R9L
C4, C7, C19, C21, C23, C25, C27, C54, C55, C56, C65, C66, C67, C71, C72, C79, C87, C88, C96, C97, C98, C106, C107, C108, C113, C129, C130, C131, C137, C139, C140, C143, C149, C155, C161, C167, C225, C226, C227, C228, C230, C306, C349, C355, C385, C397, C424, C463, C465, C469: -; RC0402JR-070RL
C5, C128: -; CL10B105KA8NNNC
C16: -; RC0201FR-0747KL
C43, C150, C156, C162, C168, C183, C191, C196, C198, C199, C200, C201, C202, C203, C204, C205, C206, C207, C208, C209, C210, C211, C212, C213, C214, C215, C216, C346, C347, C348, C350, C352, C353, C354, C356, C359, C458, C461, C464: -; FRC0402F1693TS
C53, C59, C61, C62, C68, C69, C84, C85, C92, C93, C103, C104, C111, C121, C123, C125, C127, C256, C257, C260, C262, C263, C264, C265, C266, C267, C268, C269, C270, C271, C272, C273, C274, C275, C276, C277, C278, C280, C299, C300, C301, C302, C317, C318, C319, C320, C321, C322, C323, C324, C325, C326, C327, C360, C361, C405, C407, C409, C410, C411, C412, C429, C430: -; CL03A104KP3NNNC
C57, C345, C351, C357, C358: -; 10uF_X5R_10V_0402
C60, C86, C94, C95, C119, C120, C197: -; CL05A105KQ5NNNC
C73, C74, C75, C76, C77, C78, C80, C81, C82, C89, C90, C99, C100, C101, C109, C110, C114, C115, C116, C117: -; GRM188R60J226KEA0D
C141: -; GRM31CR61A107MEA8L
C142, C459, C460: -; GRM21BR61A476ME15L
C151, C152: -; CL21A476MQYNNNE
C153, C154, C157, C158, C159, C160, C163, C164, C165, C166, C169, C170, C171, C172, C174, C175, C177, C178, C180, C181, C185, C186, C188, C189, C193, C194: -; CL10A226MQ8NRNC
C173, C176, C179, C182, C184, C187, C190, C192, C195, C462, C466, C467: -; CL10A106KP8NNNC
C223, C224, C229, C305, C395, C396, C413, C414: -; GRM21BR61H106KE43L
C231, C232, C233, C234, C235, C236, C237, C312, C313, C391, C398, C399, C400, C401: -; CL21A226KPCLRNC
C239: -; RC0201FR-07240RL
C403, C404, C408: -; VKME1001K101MV
C418, C419, C422, C423, C425, C426, C470, C471: -; RC0402FR-071KL
CN1: -; B2B-XH-2_LF_SN
CN2: -; 2199230-4_C2977809
D1, D4: -; ESD5341N-2_TR
D2, D3: -; ESD5304D-10_TR
D5, D6, D9, D10: -; B5819WS_C916992
D7, D8: -; ESD5451N-2_TR
HDMI1: -; HDMI-GD-121PWB
J2: -; PULSE_JT4-1108HL
J3: -; PinHeader_1x02_P2.54mm_Vertical
L2, L18: -; FTC322512SR22MBCA
L3, L5, L6, L7: -; APS252012MR22F
L4, L8, L9, L10, L11, L12: -; MTC201208-R47MT
L14: -; BLM18PG330SN1D
L16, L17: -; FTC404030S3R3MGCA
L19: -; FTC303020D2R2MBCA
L20: -; BLM18KG121TN1D
Q1: -; WPM3407-3_TR
Q2: -; 2SK3018T106
Q3, Q4: -; S8050-J3Y_C18221467
Q5: -; AO4407A
R1, R2, R3, R15, R16, R18: -; RC0402JR-0710KL
R4, R62, R215: -; RC0201FR-0747KL
R5: -; CRCW040222R0JNED
R6: -; RC0402FR-07510KL
R14: -; RC0402JR-071KL
R17: -; RC0402JR-0720KL
R19, R40, R56, R57, R66, R178, R203, R207, R211, R216, R217: -; RC0402FR-0710KL
R20: -; RC0402JR-0727KL
R21, R22, R31, R33, R34, R47, R48, R70, R73, R126, R128, R130, R133, R135, R143, R153, R154, R176, R208, R209, R210, R212, R214, R224, R228, R229: -; RC0402JR-070RL
R23, R24, R111, R112: -; RC0402JR-07100KL
R25: -; RC0402FR-0710RL
R26: -; RC0402FR-075K1L
R27: -; RC0402FR-0749K9L
R28: -; 0402WGF1402TCE
R29: -; RC0402FR-0768KL
R30, R199: -; RC0402FR-0733K2L
R32, R201, R202: -; RC0402FR-07100RL
R35, R61: -; RC0402FR-0712KL
R36: -; RC0402FR-073KL
R37: -; RC0402FR-076K8L
R38: -; AF0402FR-07511KL
R39: -; ARG02BTC1053
R41, R43, R44, R45, R46, R49, R51, R55, R58, R59, R60, R71, R140, R168, R180, R183, R204: -; RC0402FR-07100KL
R42: -; RC0201FR-07240RL
R50, R175: -; RC0402FR-0720KL
R52, R113, R114, R138, R205: -; RC0402FR-07120KL
R53, R54: -; RT0402BRD07200KL
R68: -; FRC0402F1693TS
R69: -; RT0603BRD0736K1L
R90: -; RC0201FR-07200KL
R136: -; RC0402FR-07300RL
R137: -; RC0402FR-071ML
R139, R141: -; RC0402FR-071KL
R142: -; RC0402FR-0715KL
R146: -; RC0402FR-072K49L
R147, R151, R206, R230, R231: -; RC0402FR-074K7L
R177: -; RT0402BRD0745K3L
R179: -; AT0402BRD0726K1L
R184: -; RT0402BRD0723K7L
R213: -; RC0402JR-0722RL
R225, R226: -; CRCW0402249RFKED
R227: -; RC0402FR-07510RL
SW1, SW2, SW3, SW4, SW5: -; TS24CA
TP1, TP2, TP3, TP4, TP5, TP6, TP7, TP9, TP10, TP23, TP24, TP25, TP26: -; TestPoint_Pad_1.0x1.0mm
U1: -; BGA1088C65P34X34_2300X2300X204N
U5: -; RS0102YH8
U6: -; TPS259804ONRGER
U11: -; RTL8125BG-CG
U12: -; WDFN-10-1EP_3x3mm_P0.5mm_EP1.8x2.5mm
U13: -; KLMBG2JETD-B041
U14: -; H9HCNNN8KUMLHR-NME
U15: -; TPS56637RPAR
U16: -; TPS2553DBVR
U18: -; QFN35P700X700X90-69N
U19: -; RCLAMP0512TQTCT
U26, U27: -; TPS563201DDCR
U28: -; RT0402BRD0752K3L
U29: -; TPS56A37RPAR
U30, U32: -; FEXL0730A-3R3M
U38, U39, U41, U42, U43, U44, U45, U47, U48, U49, U50, U51, U53, U55: -; GRM188R60J226KEA0D
U40: -; RK860-2
U46: -; SGM2576YN5G_TR
U52: -; SY8089AAAC
U54: -; RK860-3
U57: -; HYM8563S
U58: -; W25Q256JWPIQ
USB3: -; HC-TYPE-C-16P-FL6_65Q-5A-06
USBC1: -; TYPE-C-31-M-04
X1: -; XL7EL89CKI-111YLC-24M
X2: -; SC-32S32_768kHz20PPM12_5pF
X5: -; XL2EL89COI-111YLC-25M

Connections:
0V95_ETH: C312.1, C313.1, C345.2, C347.2, C348.1, C351.2, C353.1, C356.1, C357.2, C359.1, L16.2, R31.2, TP3.1 (1_1), U11.8 (DVDD09), U11.11 (AVDD09), U11.16 (AVDD09), U11.22 (AVDD09), U11.28 (DVDD09), U11.37 (EVDD09), U11.47 (DVDD09)
3V3_M0: C391.1, C398.1, C399.1, C400.1, C401.1, CN2.2 (3.3V), CN2.4 (3.3V), CN2.72 (3.3V), CN2.74 (3.3V), R176.2, TP7.1 (1_1), U32.2
/5V_USB_1: C141.2, C142.2, U16.6 (OUT), USBC1.A4 (VBUS), USBC1.A9 (VBUS), USBC1.B4 (VBUS), USBC1.B9 (VBUS)
/15V_PD_OUT: C223.2, C224.2, C225.2, C229.2, C230.2, C395.2, C396.2, C397.2, C403.1, C404.1, C408.1, C414.2, R38.2, R68.2, R140.2, TP2.1 (1_1), U6.17 (OUT), U6.18 (OUT), U6.19 (OUT), U6.20 (OUT), U6.21 (OUT), U6.22 (OUT), U6.23 (OUT), U6.24 (OUT), U15.8 (VIN), U26.3 (VIN), U29.8 (VIN)
/15V_PD_OUT_UNFUSED: C424.2, Q5.5 (D), Q5.6 (D), Q5.7 (D), Q5.8 (D), R137.2, TP1.1 (1_1), U6.1 (IN), U6.2 (IN), U6.3 (IN), U6.16 (IN), U6.25 (IN)
/ETHERNET & MAGNETICS/AVDD33_PLL_E2: C349.2, C355.2, L14.2, U11.15 (AVDD33)
/ETHERNET & MAGNETICS/CKXTAL1_E2: R153.1, U11.10 (CKXTAL1)
/ETHERNET & MAGNETICS/CKXTAL2_E2: R154.2, U11.9 (CKXTAL2)
/ETHERNET & MAGNETICS/CLKREQB_E2: R231.2, U11.48 (CLKREQB)
/ETHERNET & MAGNETICS/DVDD33_29_E2: U11.29 (DVDD33), U11.46 (DVDD33)
/ETHERNET & MAGNETICS/EVDD33_E0: C354.2, J2.1 (TRCT2), J2.6 (TRCT3), J2.7 (TRCT1), J2.12 (TRCT4), U11.43 (EVDD33)
/ETHERNET & MAGNETICS/GIP/GPO_E2: R147.2, U11.3 (GPI)
/ETHERNET & MAGNETICS/LANWAKEB_E2: R230.2, U11.2 (LANWAKEB)
/ETHERNET & MAGNETICS/LED0/EEDI/SPISI/SDA_E2: R225.1, U11.30 (LED0/EEDI/SPISI/SDA)
/ETHERNET & MAGNETICS/LED1/EESK/SPISCK_E2: R151.2, R226.1, U11.27 (LED1/EESK/SPISC)
/ETHERNET & MAGNETICS/LED2/EEDO/SPISO_E2: R228.1, U11.25 (LED2/EEDO/SPIS0)
/ETHERNET & MAGNETICS/LED3_E2: R229.1, U11.35 (LED3)
/ETHERNET & MAGNETICS/MDIN0_2: J2.9 (TRD1-), U11.14 (MDIN0)
/ETHERNET & MAGNETICS/MDIN1_2: J2.3 (TRD2-), U11.18 (MDIN1)
/ETHERNET & MAGNETICS/MDIN2_2: J2.5 (TRD3-), U11.21 (MDIN2)
/ETHERNET & MAGNETICS/MDIN3_2: J2.11 (TRD4-), U11.24 (MDIN3)
/ETHERNET & MAGNETICS/MDIP0_2: J2.8 (TRD1+), U11.13 (MDIP0)
/ETHERNET & MAGNETICS/MDIP1_2: J2.2 (TRD2+), U11.17 (MDIP1)
/ETHERNET & MAGNETICS/MDIP2_2: J2.4 (TRD3+), U11.20 (MDIP2)
/ETHERNET & MAGNETICS/MDIP3_2: J2.10 (TRD4+), U11.23 (MDIP3)
/ETHERNET & MAGNETICS/RSET_E2: R146.2, U11.12 (RSET)
/HDMIIRX_DET_L: Q4.3 (C), R24.1
/HDMI_RXDDC_SCL_PORT: HDMI1.17 (SCL), U5.2 (B1)
/HDMI_RXDDC_SDA_PORT: D1.2, HDMI1.18 (SDA), U5.3 (B2)
/MIPI DSI & CSI INTERFACES - Q | R | P/PCIE30_0_REF: R90.1, U1.B34 (PCIE30_PORT0_RESREF)
/PMIC RK806-1/PMIC_FB6: C191.1, R51.2, R52.1, U18.31 (FB6)
/PMIC RK806-1/PMIC_FB9: C183.1, R49.2, R50.1, U18.66 (FB9)
/PMIC RK806-1/PMIC_SW1: L3.1, U18.50 (SW1_2), U18.51 (SW1_1)
/PMIC RK806-1/PMIC_SW2: L5.1, U18.35 (SW2), U18.36 (SW2)
/PMIC RK806-1/PMIC_SW3: L6.1, U18.55 (SW3)
/PMIC RK806-1/PMIC_SW4: L7.1, U18.23 (SW4)
/PMIC RK806-1/PMIC_SW5: L12.1, U18.45 (SW5)
/PMIC RK806-1/PMIC_SW6: L11.1, U18.29 (SW6)
/PMIC RK806-1/PMIC_SW9: L10.1, U18.68 (SW9)
/PMIC RK806-1/PMIC_SW10: L8.1, L9.1, U18.6 (SW8), U18.26 (SW10)
/PMIC RK806-1/PMIC_VDC: C200.1, R53.1, R54.1, U18.32 (VDC)
/PMU & CLOCK - E | F/XIN_24M: C425.2, R6.1, U1.R34 (XIN_24M), X1.1
/PMU & CLOCK - E | F/XOUT_24M: R5.1, R6.2, U1.T34 (XOUT_24M)
/TYPEC_VBUS: Q5.1 (S), Q5.2 (S), Q5.3 (S), R25.2, R27.2, USB3.A4 (VBUS), USB3.A9 (VBUS), USB3.B4 (VBUS), USB3.B9 (VBUS)
/VCCIO - J | K | I/VSEL4: R111.2, U1.T32 (PMIC_SLEEP4/GPIO0_C2_D)
/VCCIO - J | K | I/VSEL5: R112.2, U1.T30 (PMIC_SLEEP5/GPIO0_C3_D)
BIG/NPU_EN: U40.A2 (EN), U54.A2 (EN)
BOOT_SARADC_IN0: C314.2, R41.1, R135.2, TP9.1 (1_1), U1.AM16 (SARADC_IN0_BOOT)
CPU_BIG1_VSEL: U1.W28 (PMIC_SLEEP6/PDM0_SDI3_M1/GPIO0_D6_D), U54.A1 (VSEL)
DDR_CH0_A0_A: U1.T7 (DDR_CH0_A0_A), U14.H2 (CA0a)
DDR_CH0_A0_B: U1.M8 (DDR_CH0_A0_B), U14.R2 (CA0b)
DDR_CH0_A1_A: U1.T8 (DDR_CH0_A1_A), U14.J2 (CA1a)
DDR_CH0_A1_B: U1.M5 (DDR_CH0_A1_B), U14.P2 (CA1b)
DDR_CH0_A2_A: U1.P4 (DDR_CH0_A2_A), U14.H9 (CA2a)
DDR_CH0_A2_B: U1.N5 (DDR_CH0_A2_B), U14.R9 (CA2b)
DDR_CH0_A3_A: U1.P5 (DDR_CH0_A3_A), U14.H10 (CA3a)
DDR_CH0_A3_B: U1.N4 (DDR_CH0_A3_B), U14.R10 (CA3b)
DDR_CH0_A4_A: U1.R1 (DDR_CH0_A4_A), U14.H11 (CA4a)
DDR_CH0_A4_B: U1.K1 (DDR_CH0_A4_B), U14.R11 (CA4b)
DDR_CH0_A5_A: U1.P2 (DDR_CH0_A5_A), U14.J11 (CA5a)
DDR_CH0_A5_B: U1.L2 (DDR_CH0_A5_B), U14.P11 (CA5b)
DDR_CH0_CLKN_A: U1.N1 (DDR_CH0_CKB_A), U14.J9 (CK_ca)
DDR_CH0_CLKN_B: U1.M1 (DDR_CH0_CKB_B), U14.P9 (CK_cb)
DDR_CH0_CLKP_A: U1.N2 (DDR_CH0_CK_A), U14.J8 (CK_ta)
DDR_CH0_CLKP_B: U1.M2 (DDR_CH0_CK_B), U14.P8 (CK_tb)
DDR_CH0_DM0_A: U1.Y4 (DDR_CH0_DM0_A), U14.C3 (DMI0a)
DDR_CH0_DM0_B: U1.G4 (DDR_CH0_DM0_B), U14.Y3 (DMI0b)
DDR_CH0_DM1_A: U1.AB4 (DDR_CH0_DM1_A), U14.C10 (DMI1a)
DDR_CH0_DM1_B: U1.E4 (DDR_CH0_DM1_B), U14.Y10 (DMI1b)
DDR_CH0_DQ0_A: U1.U1 (DDR_CH0_DQ0_A), U14.B2 (DQ0a)
DDR_CH0_DQ0_B: U1.H1 (DDR_CH0_DQ0_B), U14.AA2 (DQ0b)
DDR_CH0_DQ1_A: U1.T2 (DDR_CH0_DQ1_A), U14.C2 (DQ1a)
DDR_CH0_DQ1_B: U1.J2 (DDR_CH0_DQ1_B), U14.Y2 (DQ1b)
DDR_CH0_DQ2_A: U1.T1 (DDR_CH0_DQ2_A), U14.E2 (DQ2a)
DDR_CH0_DQ2_B: U1.J1 (DDR_CH0_DQ2_B), U14.V2 (DQ2b)
DDR_CH0_DQ3_A: U1.R2 (DDR_CH0_DQ3_A), U14.F2 (DQ3a)
DDR_CH0_DQ3_B: U1.K2 (DDR_CH0_DQ3_B), U14.U2 (DQ3b)
DDR_CH0_DQ4_A: U1.W1 (DDR_CH0_DQ4_A), U14.F4 (DQ4a)
DDR_CH0_DQ4_B: U1.F1 (DDR_CH0_DQ4_B), U14.U4 (DQ4b)
DDR_CH0_DQ5_A: U1.V2 (DDR_CH0_DQ5_A), U14.E4 (DQ5a)
DDR_CH0_DQ5_B: U1.G2 (DDR_CH0_DQ5_B), U14.V4 (DQ5b)
DDR_CH0_DQ6_A: U1.V1 (DDR_CH0_DQ6_A), U14.C4 (DQ6a)
DDR_CH0_DQ6_B: U1.G1 (DDR_CH0_DQ6_B), U14.Y4 (DQ6b)
DDR_CH0_DQ7_A: U1.U2 (DDR_CH0_DQ7_A), U14.B4 (DQ7a)
DDR_CH0_DQ7_B: U1.H2 (DDR_CH0_DQ7_B), U14.AA4 (DQ7b)
DDR_CH0_DQ8_A: U1.AB2 (DDR_CH0_DQ8_A), U14.B11 (DQ8a)
DDR_CH0_DQ8_B: U1.D2 (DDR_CH0_DQ8_B), U14.AA11 (DQ8b)
DDR_CH0_DQ9_A: U1.AB1 (DDR_CH0_DQ9_A), U14.C11 (DQ9a)
DDR_CH0_DQ9_B: U1.C1 (DDR_CH0_DQ9_B), U14.Y11 (DQ9b)
DDR_CH0_DQ10_A: U1.AC1 (DDR_CH0_DQ10_A), U14.E11 (DQ10a)
DDR_CH0_DQ10_B: U1.C2 (DDR_CH0_DQ10_B), U14.V11 (DQ10b)
DDR_CH0_DQ11_A: U1.AC2 (DDR_CH0_DQ11_A), U14.F11 (DQ11a)
DDR_CH0_DQ11_B: U1.B1 (DDR_CH0_DQ11_B), U14.U11 (DQ11b)
DDR_CH0_DQ12_A: U1.Y1 (DDR_CH0_DQ12_A), U14.F9 (DQ12a)
DDR_CH0_DQ12_B: U1.F2 (DDR_CH0_DQ12_B), U14.U9 (DQ12b)
DDR_CH0_DQ13_A: U1.Y2 (DDR_CH0_DQ13_A), U14.E9 (DQ13a)
DDR_CH0_DQ13_B: U1.E1 (DDR_CH0_DQ13_B), U14.V9 (DQ13b)
DDR_CH0_DQ14_A: U1.AA1 (DDR_CH0_DQ14_A), U14.C9 (DQ14a)
DDR_CH0_DQ14_B: U1.E2 (DDR_CH0_DQ14_B), U14.Y9 (DQ14b)
DDR_CH0_DQ15_A: U1.AA2 (DDR_CH0_DQ15_A), U14.B9 (DQ15a)
DDR_CH0_DQ15_B: U1.D1 (DDR_CH0_DQ15_B), U14.AA9 (DQ15b)
DDR_CH0_DQS0_A_N: U1.U4 (DDR_CH0_DQS0N_A), U14.E3 (DQS0_ca)
DDR_CH0_DQS0_A_P: U1.U5 (DDR_CH0_DQS0P_A), U14.D3 (DQS0_ta)
DDR_CH0_DQS0_B_N: U1.J7 (DDR_CH0_DQS0N_B), U14.V3 (DQS0_cb)
DDR_CH0_DQS0_B_P: U1.J8 (DDR_CH0_DQS0P_B), U14.W3 (DQS0_tb)
DDR_CH0_DQS1_A_N: U1.AA4 (DDR_CH0_DQS1N_A), U14.E10 (DQS1_ca)
DDR_CH0_DQS1_A_P: U1.AA5 (DDR_CH0_DQS1P_A), U14.D10 (DQS1_ta)
DDR_CH0_DQS1_B_N: U1.F4 (DDR_CH0_DQS1N_B), U14.V10 (DQS1_cb)
DDR_CH0_DQS1_B_P: U1.F5 (DDR_CH0_DQS1P_B), U14.W10 (DQS1_tb)
DDR_CH0_LP4/4X_CS0_A: U1.R6 (DDR_CH0_LP4/4X_CS0_A), U14.H4 (CS0a)
DDR_CH0_LP4/4X_CS0_B: U1.L7 (DDR_CH0_LP4/4X_CS0_B), U14.R4 (CS0b)
DDR_CH1_LP4/4X_CKE0_C: U1.D16 (DDR_CH1_LP4/4X_CKE0/LP5_CS0_D), U1.E19 (DDR_CH1_LP4/4X_CS0_D)
DDR_CH1_LP4/4X_CKE1_C: U1.D19 (DDR_CH1_LP4/4X_CS1_D), U1.E16 (DDR_CH1_LP4/4X_CKE1/LP5_CS1_D)
DDR_RESET: C239.1, U1.T4 (DDR_CH0_RESET_A), U14.T11 (RESET)
FSPI_CLK: U1.AE33 (GMAC0_TXCLK/SDIO_CLK_M0/FSPI_CLK_M1/I2C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), U58.6 (CLK)
FSPI_CS0: U1.AB31 (GMAC0_PTP_REFCLK/FSPI_CS0N_M1/HDMI_TX1_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), U58.1 (CS#)
FSPI_D0: U1.AC32 (GMAC0_RXD2/SDIO_D0_M0/FSPI_D0_M1/UART6_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), U58.5 (DI(IO0))
FSPI_D1: U1.AC31 (GMAC0_RXD3/SDIO_D1_M0/FSPI_D1_M1/UART6_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), U58.2 (DO(IO1))
FSPI_D2: R217.2, U1.AE32 (GMAC0_RXCLK/SDIO_D2_M0/FSPI_D2_M1/I2C8_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), U58.3 (WP#(IO2))
FSPI_D3: R216.2, U1.AC33 (GMAC0_TXD2/SDIO_D3_M0/FSPI_D3_M1/I2C8_S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), U58.7 (HOLD#orRESET#(IO3))
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
